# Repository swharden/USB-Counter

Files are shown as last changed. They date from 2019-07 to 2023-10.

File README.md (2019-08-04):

# USB Counter

This project contains the design files and notes for a USB counter. By populating one of two input paths with components this device can serve as a sensitive frequency counter (with a small-signal amplifier front-end) or a pulse counter (with a simple 50 ohm load at the front-end). Measured frequency is sent to the computer over USB, but can also be displayed on an optional 7-segment display module.

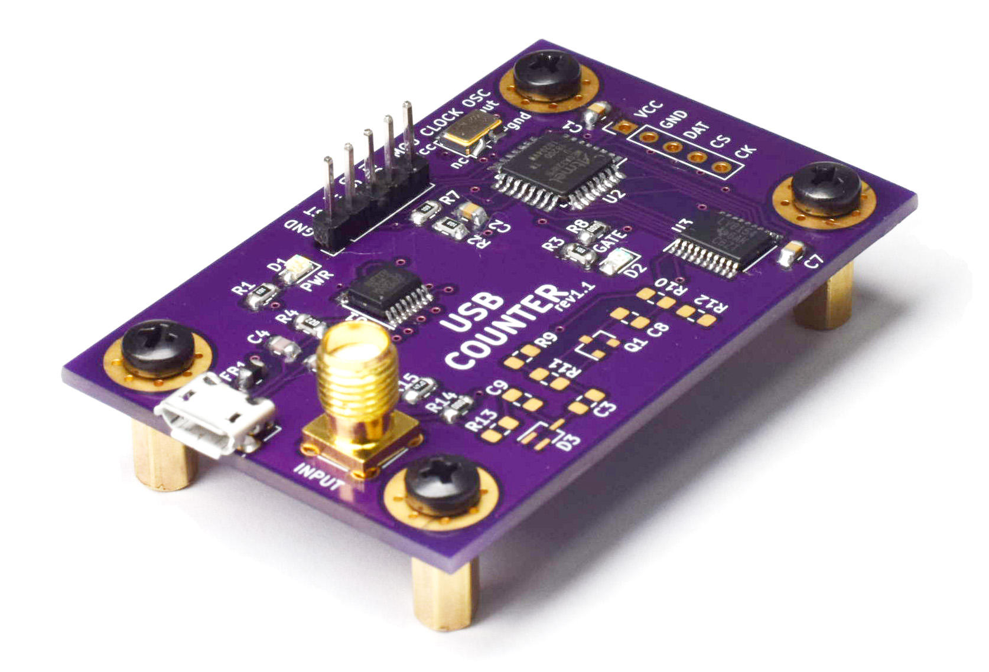
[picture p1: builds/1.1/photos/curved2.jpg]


### LED Display

In addition to serial output, this counter can optionally interface a SPI-driven 7-segment display (based on a MAX7219). These display modules are about [$4 on Amazon](https://www.amazon.com/s?k=max7219+segment) and allow this counter to be used without a computer. Note that the LED display and USB output can both be used at the same time.

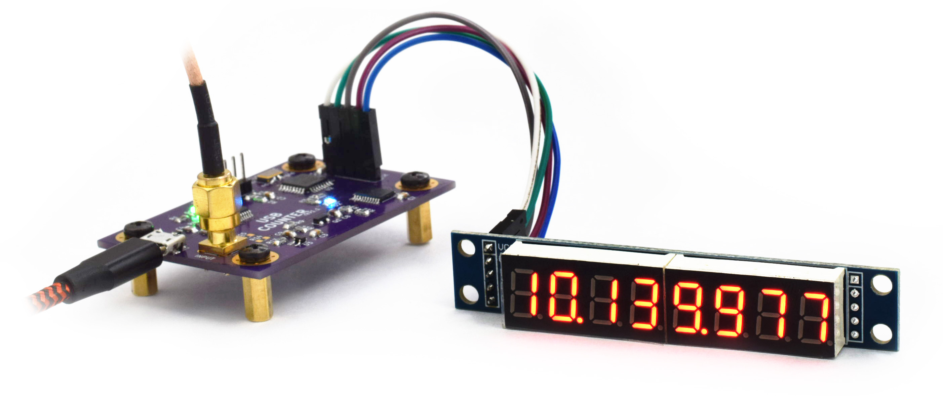
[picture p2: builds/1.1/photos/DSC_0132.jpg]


### USB (Serial) Output

When plugged in to a USB port the counter looks like a serial device. It continuously transmits the count (at 115200 baud) at an update rate which can be customized (commonly 1Hz, 10Hz, and 100Hz.) The output is two numbers: time (in seconds) and the count between the last update and this one. In this example it is measuring a radio frequency signal near 10.139977 MHz

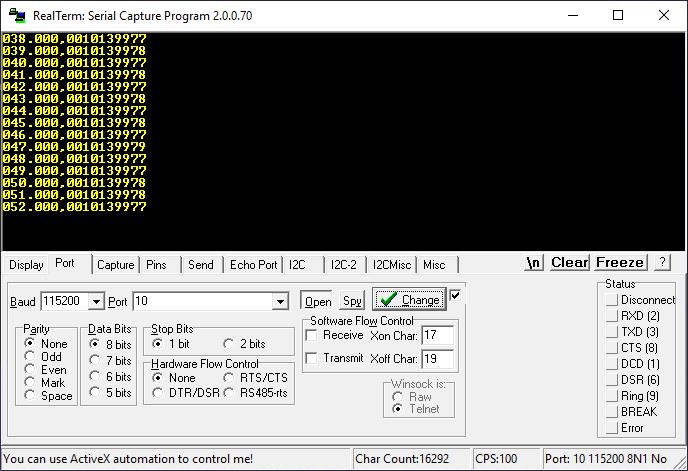
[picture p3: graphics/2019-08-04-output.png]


### Precision Frequency Measurement

One advantage of this counter is that it is never reset. Its core is a 32-bit counter, and every gate cycle transmits the current count to the computer over USB. Because every input cycle is measured high precision measurements of frequency over long periods of time are possible. For example, 1000 repeated measurements with a 1Hz gate allows frequency measurement to a precision of 0.01 Hz.

### Internal or External Gating
The microcontroller is capable of generating gate cycles in software. Precision is limited to that of the TCXO used to clock the microcontroller (2.5 PPM). For higher-precision gating a resistor may be lifted and an external gate applied (e.g., 1PPS GPS signal).

### Design and Build Notes

* [Revision 1.0 - schematics and PCB design](/builds/1.0) - first tested 2019-07-26
* [Revision 1.1 - schematics and PCB design](/builds/1.1) - first tested 2019-08-03

### About

This project was created by [Harden Technologies, LLC](http://tech.swharden.com). To inquire about the development special features or customized versions of this hardware or software, contact the author at [SWHarden@gmail.com](mailto:swharden@gmail.com).

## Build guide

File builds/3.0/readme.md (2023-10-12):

# Talking Frequency Counter

This version of the frequency counter uses USB for power (not connectivity) and speaks frequency out loud when a button is pressed. Once finished this project will probably be moved into its own repository.

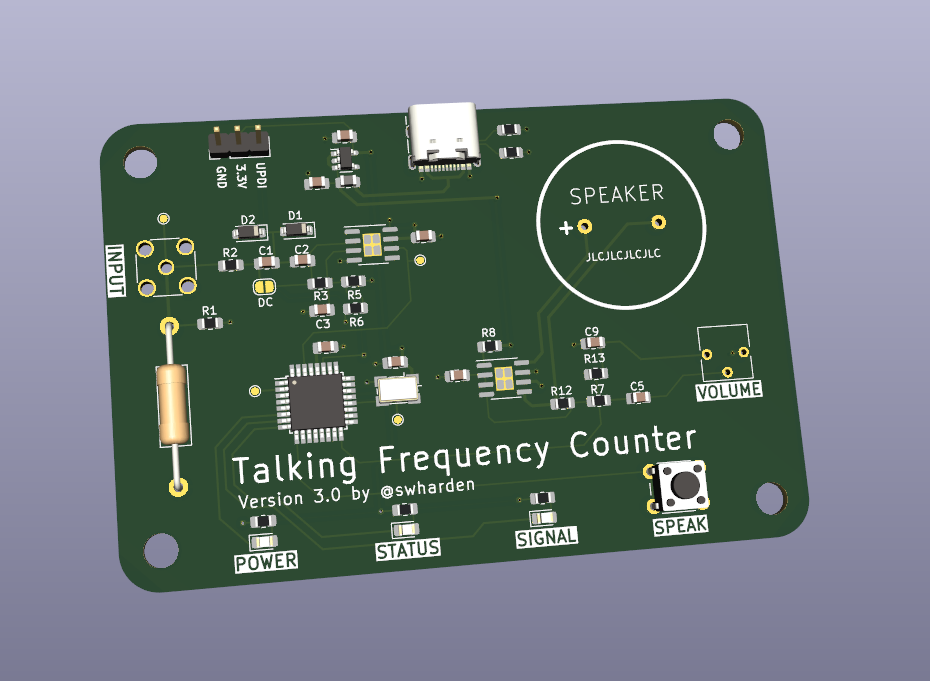
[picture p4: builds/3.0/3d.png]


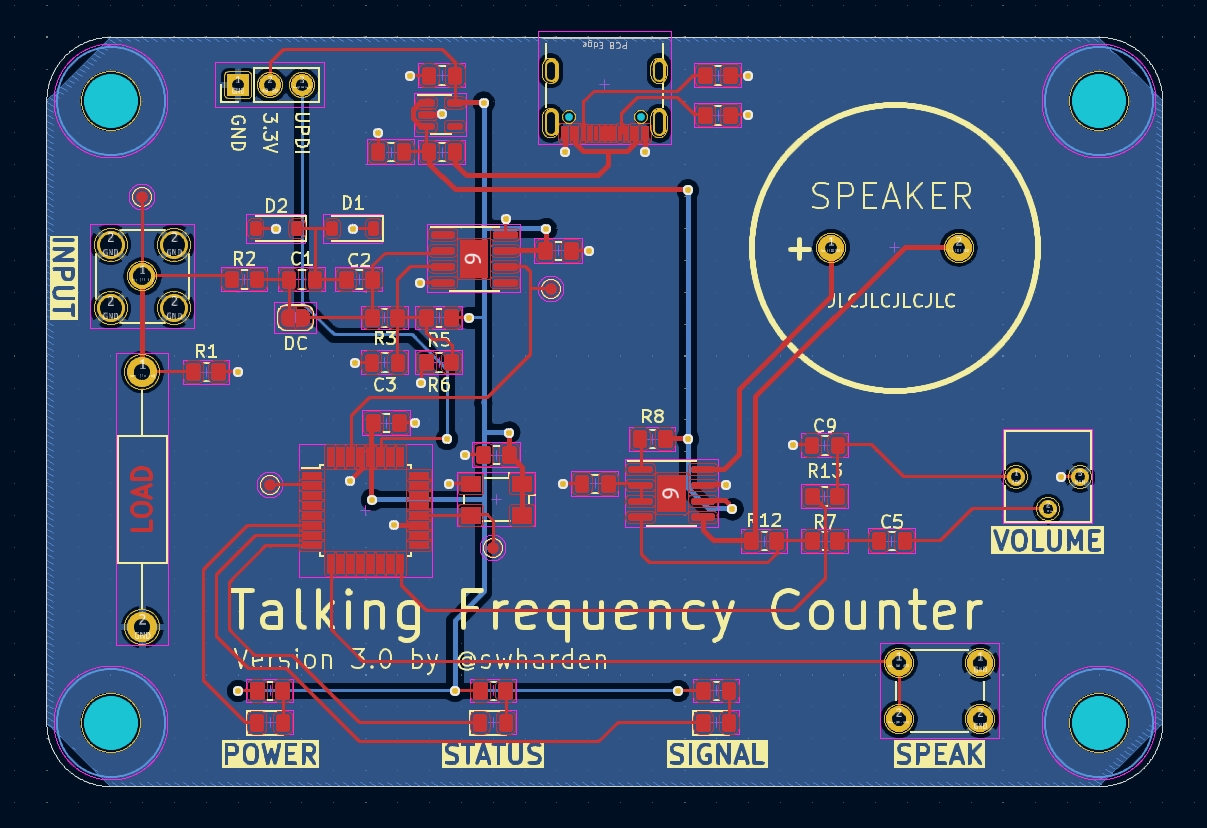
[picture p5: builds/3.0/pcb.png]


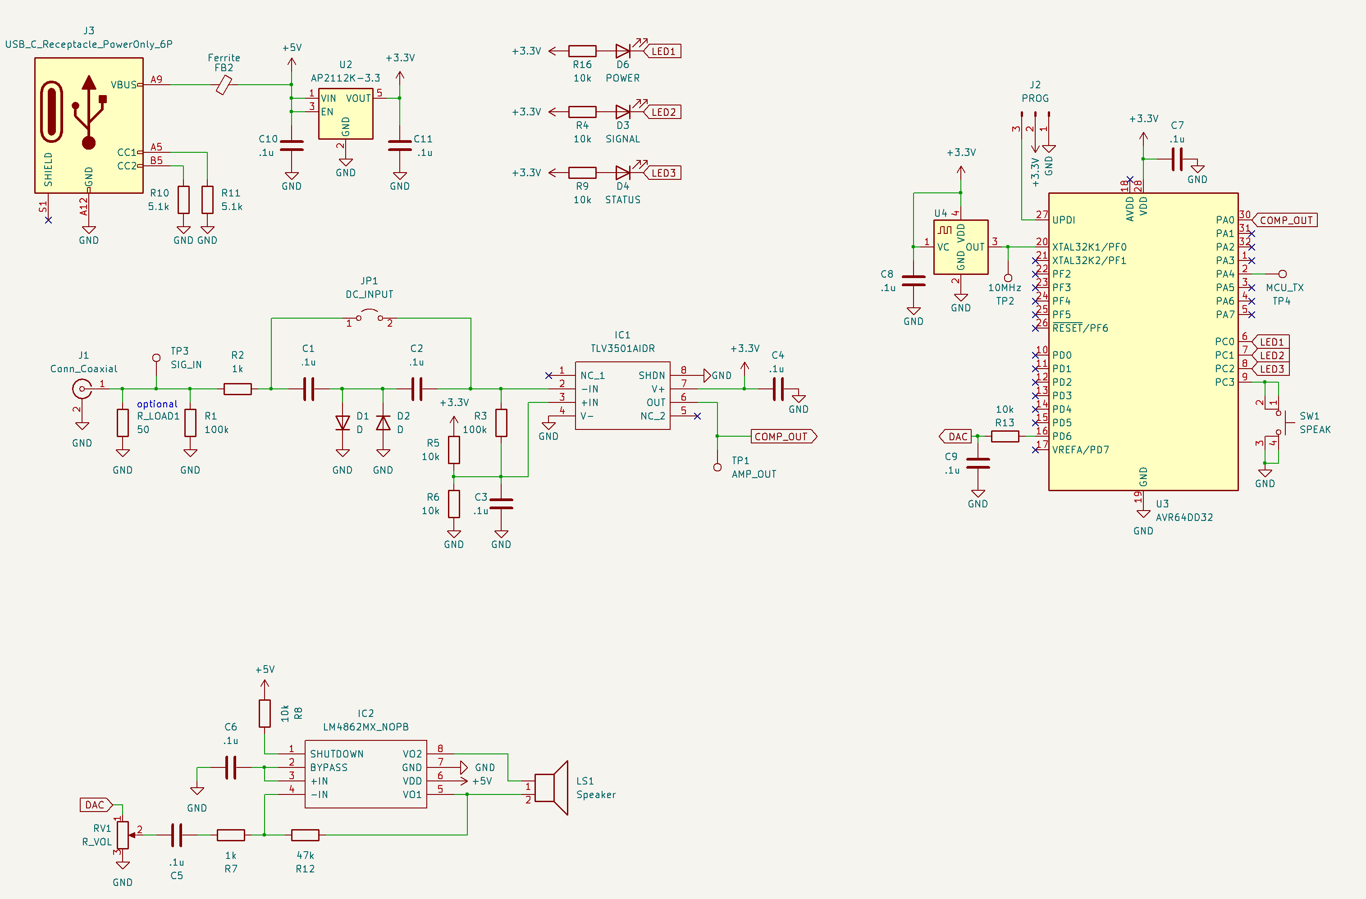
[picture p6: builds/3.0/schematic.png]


## Build Notes

* VDDIO2 should be connected to 3.3V (required bodge wire)
* Crystal pads are silly big
* Audio amplifier shutdown should be pulled LOW not HIGH
* Volume knob is wired backwards
* Rename header 3.3v to VCC
* Button is wired incorrectly (always grounded)
* Move header closer to the edge or use different system
* Don't use port C for LEDs or button

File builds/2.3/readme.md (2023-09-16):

# Talking Frequency Counter

This folder contains design notes for a ***talking frequency counter*** designed to help visually impaired radio operators to know what frequency they are transmitting on by speaking the frequency out loud when a button is pressed. This design uses a high-speed analog comparator to amplify signals on the frontend, measures them directly with a microcontroller, sends that data to a PC using a USB serial adapter, and also says the frequency out loud using a speaker.

> **⚠️ WARNING:** This is a work in progress. This board design has some errors which will be corrected in a future build.

## Components
* **AP2112K-3.3TRG1** 600 mA 3.3V LDO regulator ([$0.35 from Mouser](https://www.mouser.com/ProductDetail/Diodes-Incorporated/AP2112K-3.3TRG1?qs=x6A8l6qLYDDPYHosCdzh%2FA%3D%3D))
* **AVR64DD32** 8-bit microcontroller ([$1.51 on Mouser](https://www.mouser.com/ProductDetail/Microchip-Technology/AVR64DD32-I-PT?qs=tlsG%2FOw5FFjuwvYsegdIqg%3D%3D))
* **Oscillator** 10 MHz oscillator, 3.3V, ±2.5 ppm ([$1.89 on Mouser](https://www.mouser.com/ProductDetail/ECS/ECS-TXO-2016-33-100-TR?qs=PzGy0jfpSMvd6OxkHIkpfg%3D%3D))
* **TLV3501** high speed analog comparator ([$3.06 on Mouser](https://www.mouser.com/ProductDetail/Texas-Instruments/TLV3501AIDR?qs=m96fseALk3U7ir0PfDMQ%252BA%3D%3D))
* **LM4862** audio amplifier ([$1.21 on Mouser](https://www.mouser.com/ProductDetail/Texas-Instruments/LM4862MX-NOPB?qs=QbsRYf82W3HZp12WHQE14A%3D%3D))
* **FT231** USB Serial Adapter ([$2.33 on Mouser](https://www.mouser.com/ProductDetail/FTDI/FT231XS-R?qs=Gp1Yz1mis3WduRPsgrTbtg%3D%3D))
* **Diode** 100V 4A 4ns recovery ([$0.13 on Mouser](https://www.mouser.com/ProductDetail/Panjit/1N4148W_R1_00001?qs=sPbYRqrBIVnqVztCqPNVrw%3D%3D))
* **Speaker** 8Ω 300 mW ([$2.09 on Mouser](https://www.mouser.com/ProductDetail/DB-Unlimited/SM231508-1?qs=t9M3m0YJX4Ng139DBuQXjw%3D%3D))
* **USB Connector** type B micro ([$0.46 on Mouser](https://www.mouser.com/ProductDetail/Amphenol-FCI/10118193-0001LF?qs=Ywefl8B65e63Nsqd%252B8HZaQ%3D%3D))
* **USB Connector (next time)** use USBC ([$0.80 on Mouser](https://www.mouser.com/ProductDetail/GCT/USB4105-GF-A?qs=KUoIvG%2F9IlY%2FMLlBMpStpA%3D%3D))
* **0802 Components** are purchased in bulk and essentially free
* **Bumpers** for raising the PCB ([Bumpon SJ5076 from eBay](https://www.mouser.com/datasheet/2/1/Bumpon%20Molded%20Shapes%20Colored%20and%20Clear%20Series%20TDS-845047.pdf))

_Approximately $13 total_

## Schematic

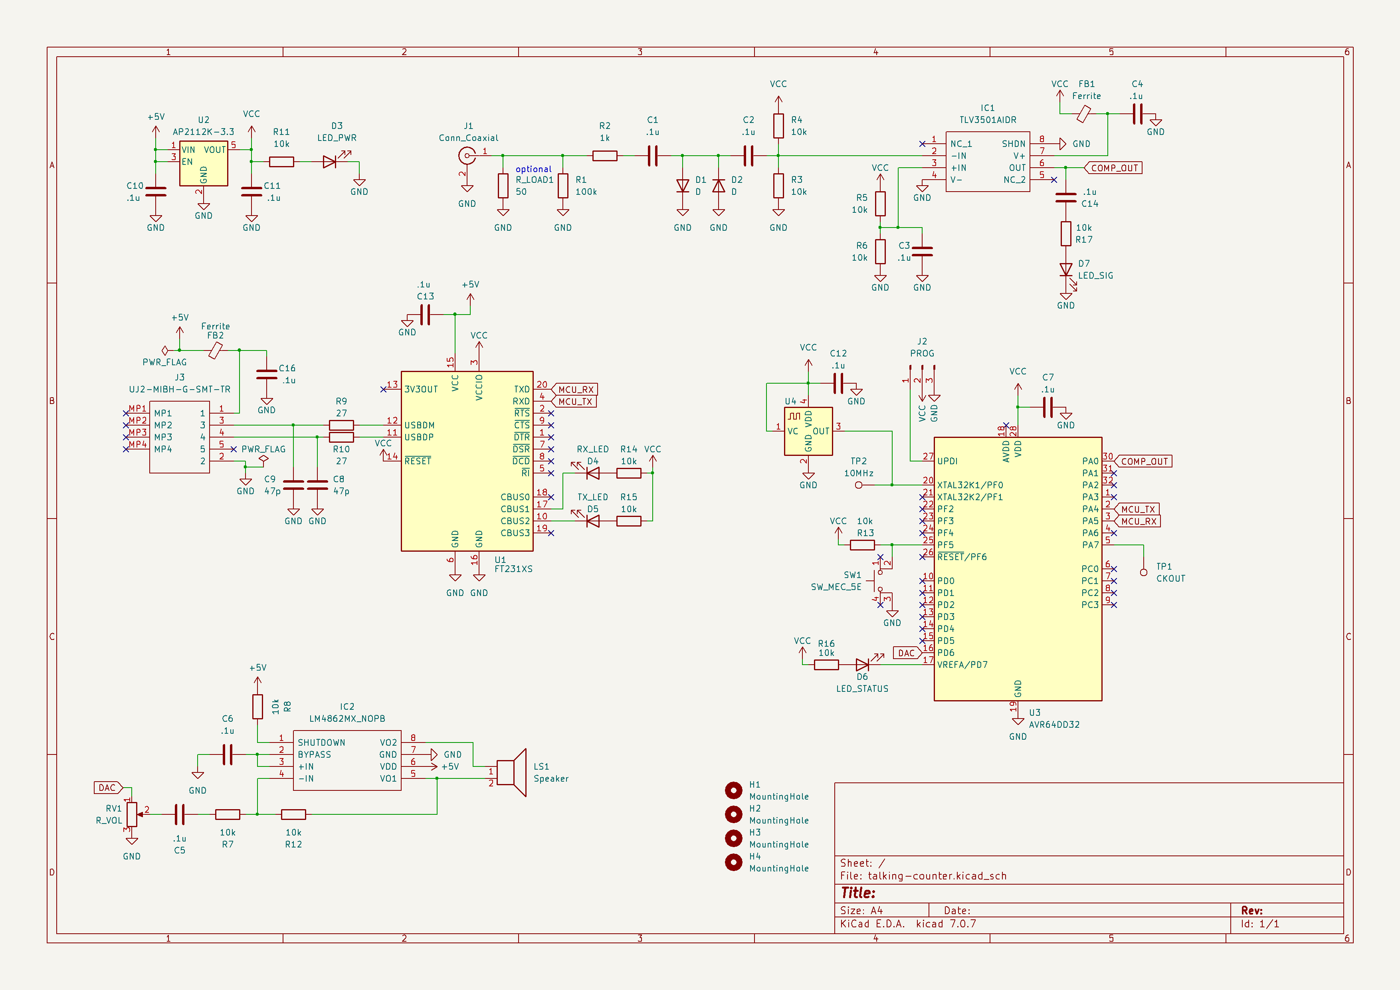
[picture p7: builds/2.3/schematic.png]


## Preview Render

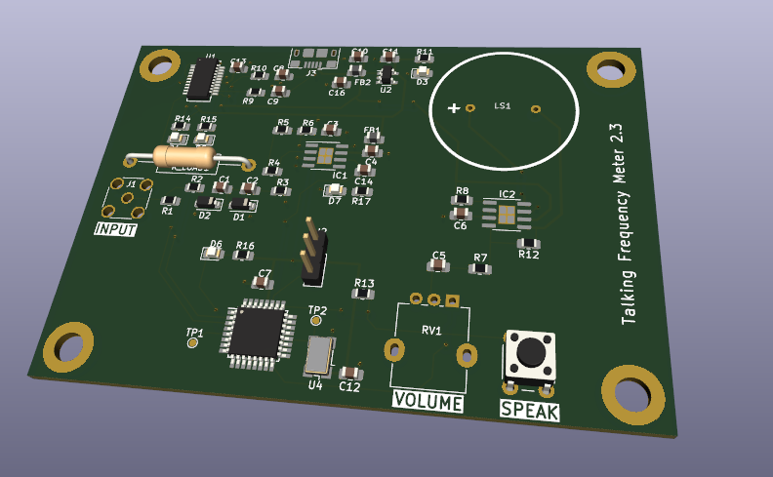
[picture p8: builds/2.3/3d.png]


## Resources

* [100 MHz frequency counter](https://www.electronics-lab.com/project/100mhz-frequency-counter-with-pic16f628a-2/) (designed by Hristo) uses the TLV3501 for its frontend

* [Frequency Measurement with Modern AVR Microcontrollers](https://swharden.com/blog/2023-08-31-avr-dd-frequency-counter/)

* [Play Audio from SPI Flash with a Microcontroller](https://swharden.com/blog/2023-08-26-spi-flash-audio/)

* [Speaking Numbers with a Microcontroller](https://swharden.com/blog/2023-08-19-speaking-microcontroller/)

## Photo

Oof that's a lot of bodges

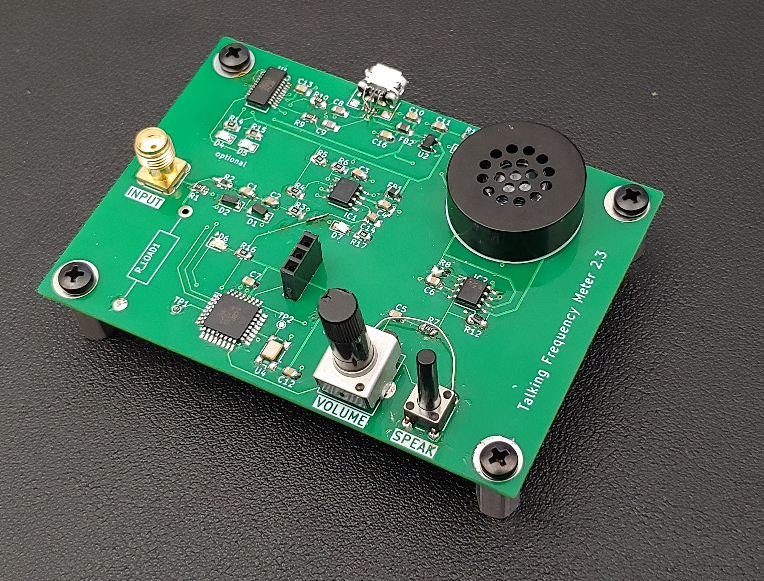
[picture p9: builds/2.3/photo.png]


## Notes During the Build
* PCB edges should be rounded
* Green LEDs should have 47k resistors (not 10k)
* USB lines are incorrect. They should be:
  * 1. VCC
  * 2. ?
  * 3. ?
  * 4. ID (nc)
  * 5. GND
* Need to order more .1 µF caps
* Speaker holes should be bigger
* Volume knob holes should be bigger
* Volume knob polarity should be reversed
* Label programmer pins
* Amplifier shutdown pin should be grounded (not tied to VCC)
* Amplifier resistors should be R12=47k and R7=1k
* The button is wired wrong. Bottom right pin should be grounded.
* Test points should be labeled.
* Add a test point for comparator input and output.
* Ground screw holes.
* Omit RX led (only TX needed)
* Use smaller volume knob and move it away from the button
* Speaker hides power LED
* Move prog header to edge of board
* The load resistor "optional" label is floating beneath the RX/TX leds
* Omit C14 and replace R17 with a 1k resistor
* Use green LEDs everywhere
* Fix the double-press issue
* RF front-end: use a dual diode
* RF front-end: don't tap COMP_OUT with a LED (do that in software)
* Just add TX test pad (not FTDI chip)
* Load comparator output
* Jumper to bypass AC coupling on input

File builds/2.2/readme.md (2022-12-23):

# Version 2.2

## Thoughts

* Make an RF amplifier board separately (perhaps with prescaler)
* Input should be 0-5V TTL
* What makes this unique is no-cycle-lost counting
* Ability to accept a 10 MHz lab reference clock is also a big win

## Build notes
* Red and blue LEDs need 1K resistors
* Green LEDs need 47k resistors
* Capacitors on USB line should be 47pF
* LJCPCB blue silkscreen is ugly and doesn't hold up to heat as well as green
* For the crystal oscillator indicate where the dot goes
* It's annoying to keep rotating the board when hand assembling so lay-out passives horizontally
* Move the board ID under one of the ICs
* Consider horizontally mounted headers and SMA connector to facilitate stacking
* Clamp diodes should be downstream of the input decoupling decapacitors
* External 10MHz clock is going into the wrong pin (32 kHz clock). Clock should go to PA0/PA1 and USART use alternate pins PD4/PD5

## Schematic

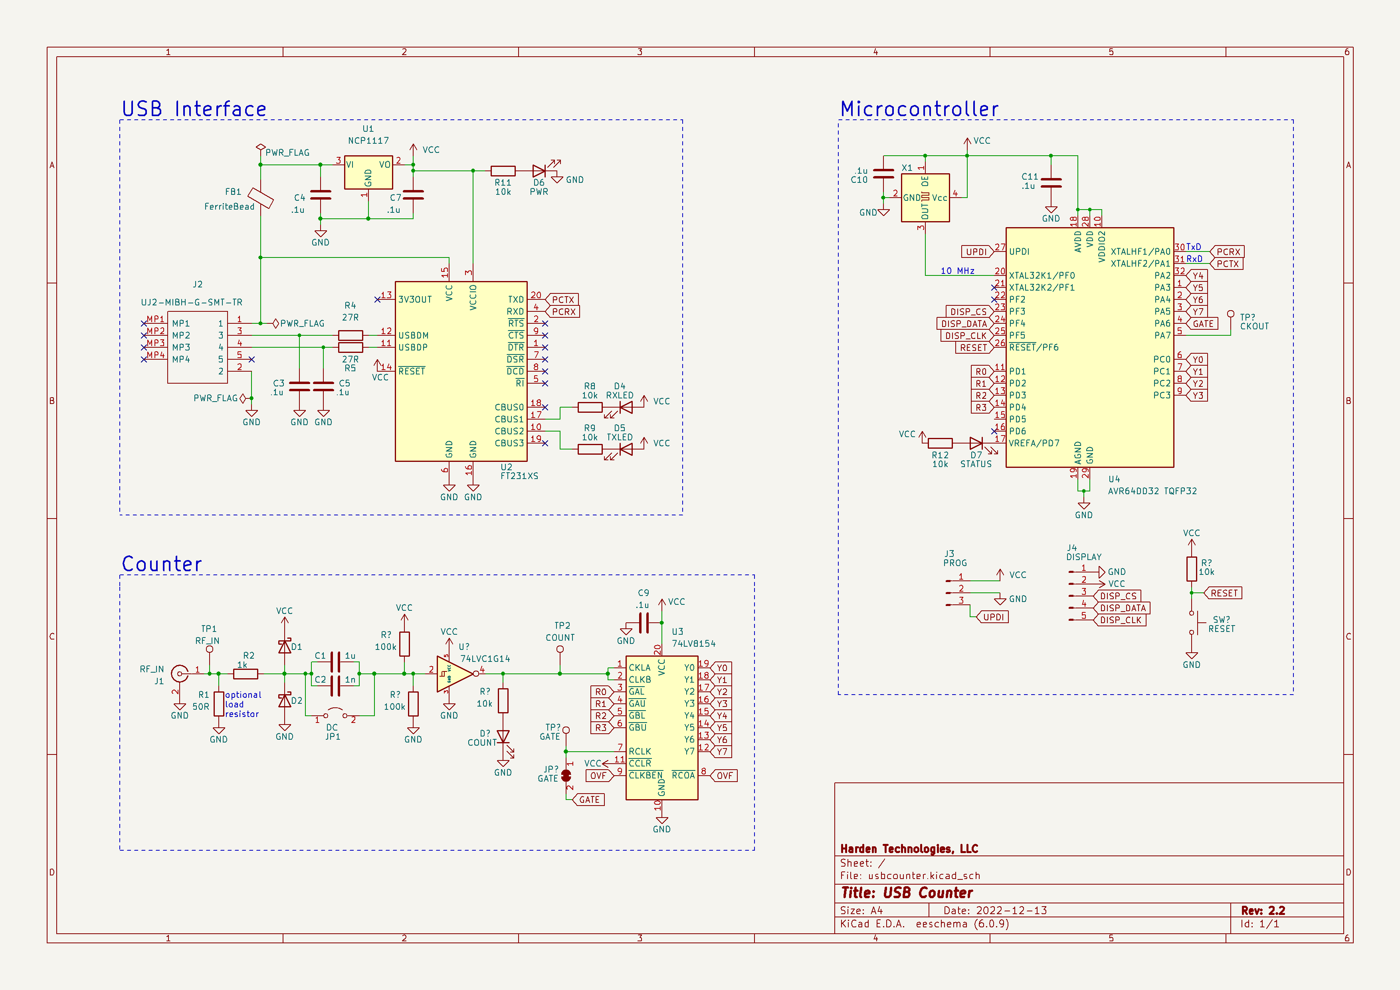
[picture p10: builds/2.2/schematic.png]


## Alternative Frontend Designs

### TLV3501 RF Comparator
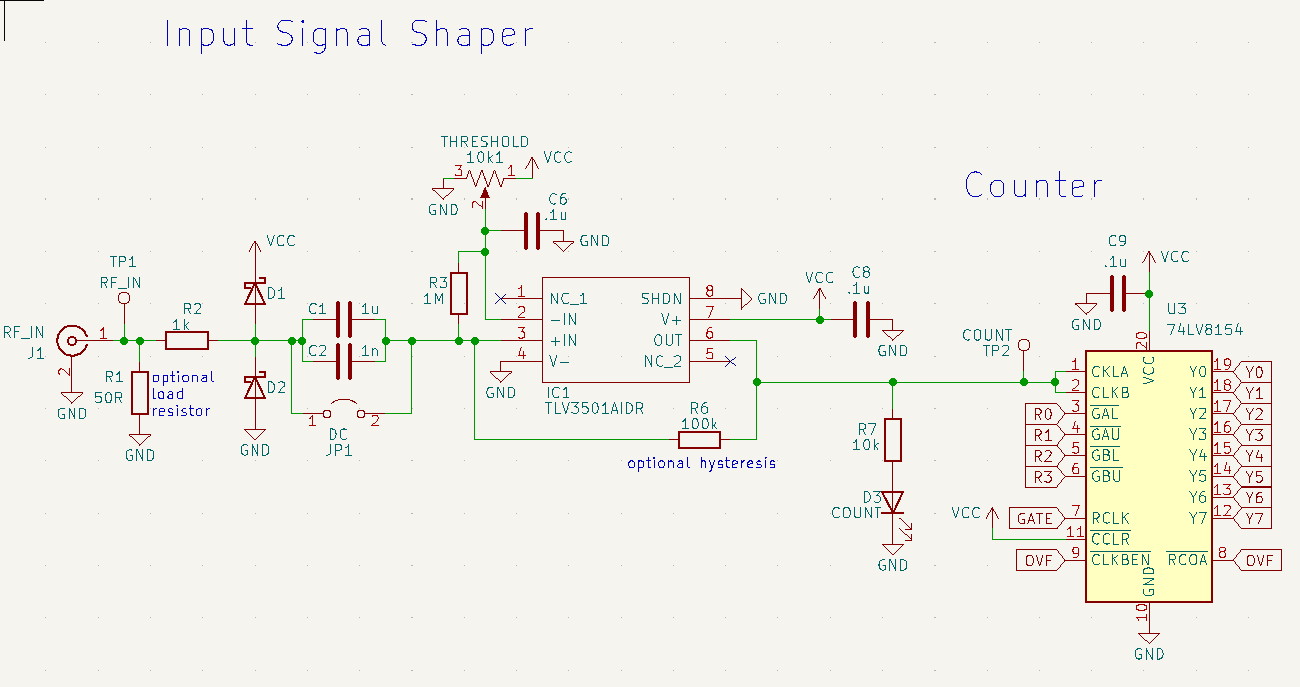
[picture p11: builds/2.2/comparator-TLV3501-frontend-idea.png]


### OPA356 RF Opamp
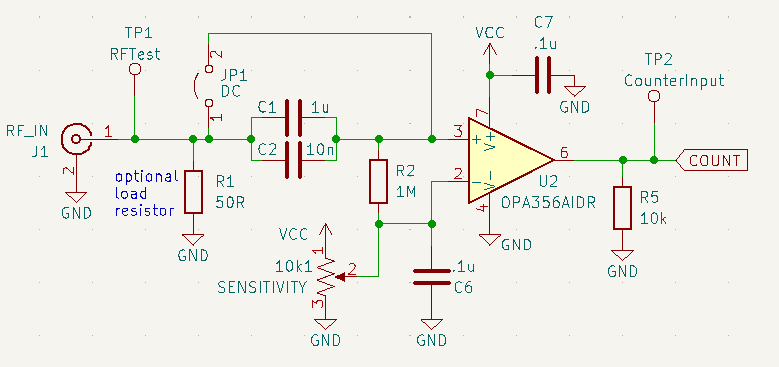
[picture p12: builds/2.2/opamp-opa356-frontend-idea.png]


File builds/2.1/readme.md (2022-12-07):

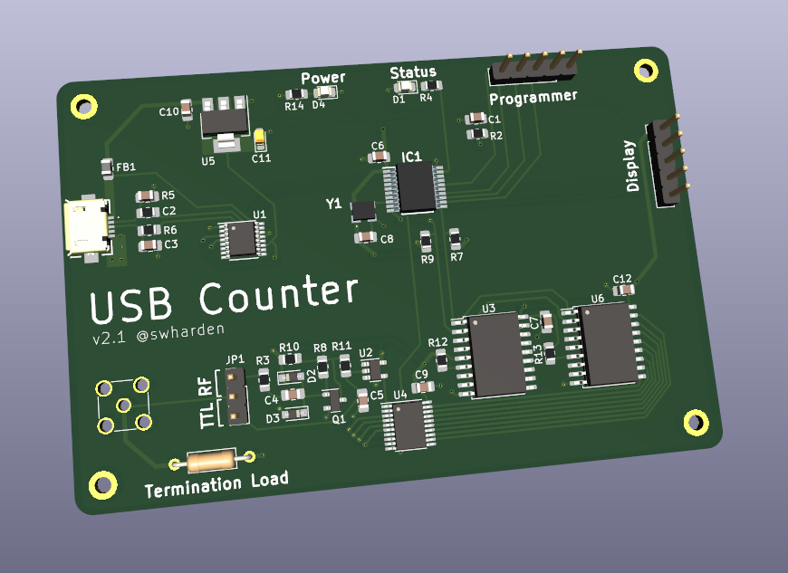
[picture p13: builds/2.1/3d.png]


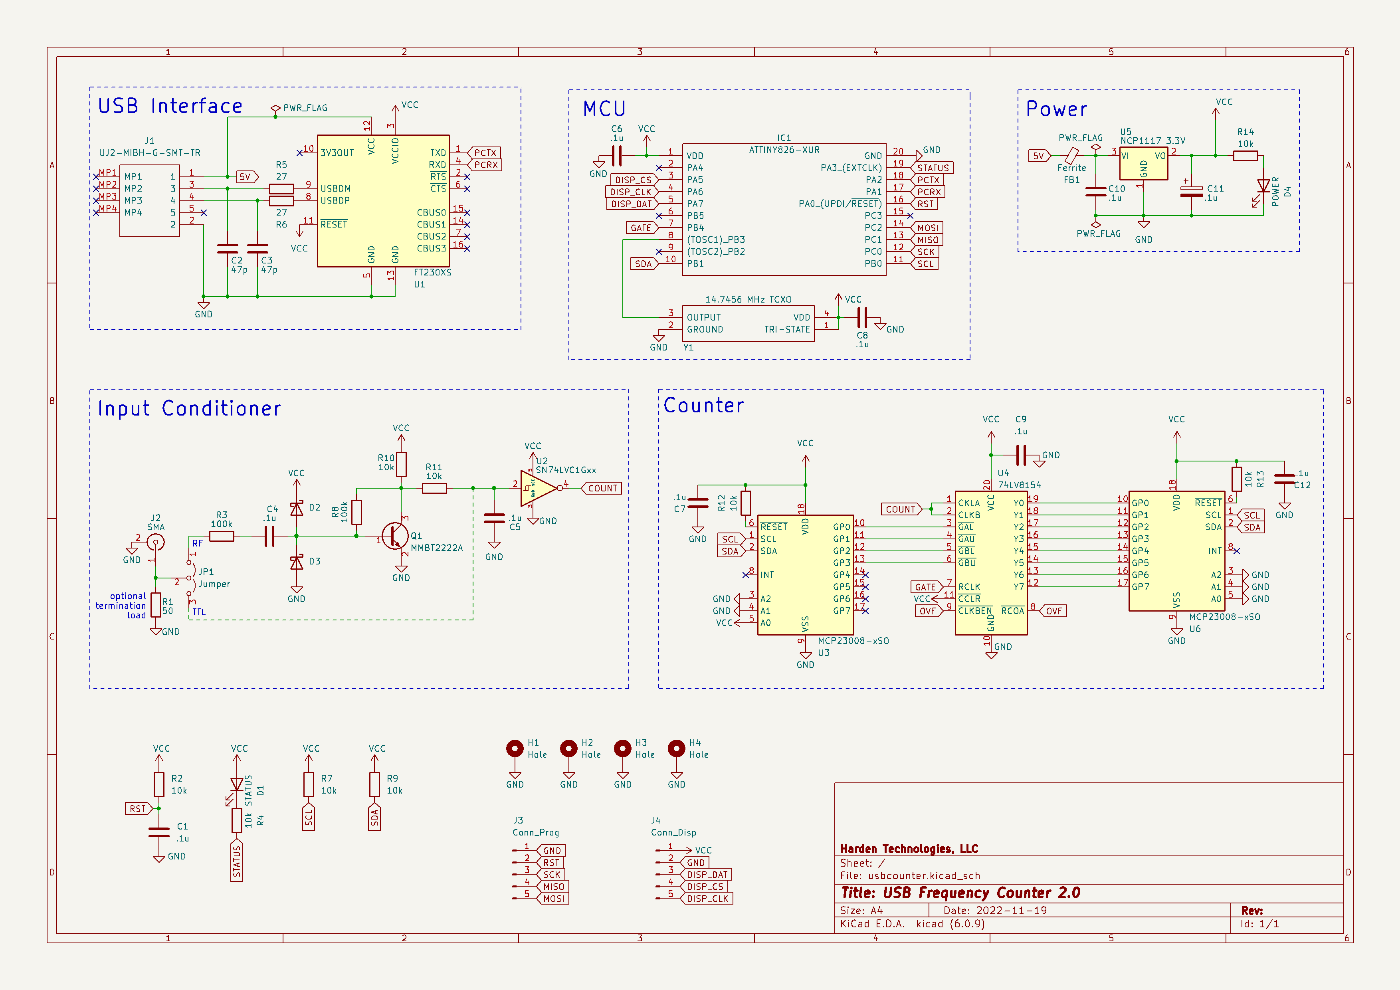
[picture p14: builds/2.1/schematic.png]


## Notes

* Design around FT231 (not FT230) for improved supply chain availability
* PCB labels for R5 and C2 are reversed
* ICs need dot near pin 1
* favor USBC port
* dot for oscillator
* screw holes are too small
* pins need labels
* MCU programming pins are wrong - this chip only supports UPDI
* Frontend sucks. Check out better [buffer](http://www.muzique.com/lab/buffers.htm) frontends.

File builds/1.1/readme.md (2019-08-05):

# USB Frequency Counter (rev 1.1)

* I ordered this PCB on 2019-07-28
* I built this device on 2019-08-03

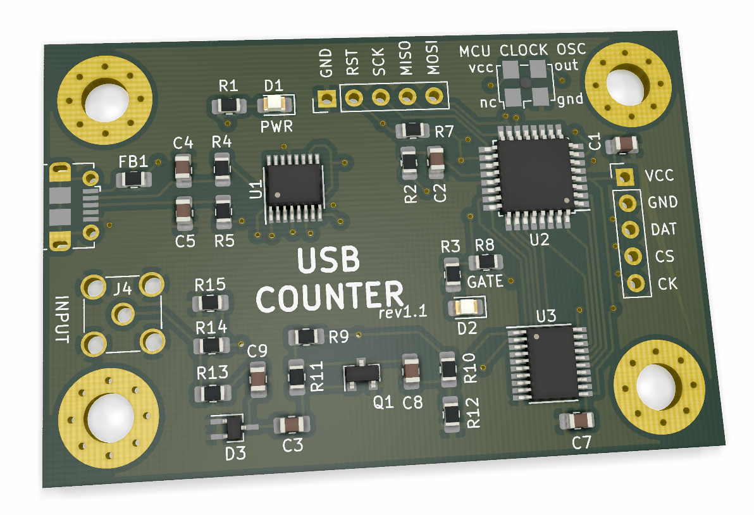
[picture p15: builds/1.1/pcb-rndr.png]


### PCB Design
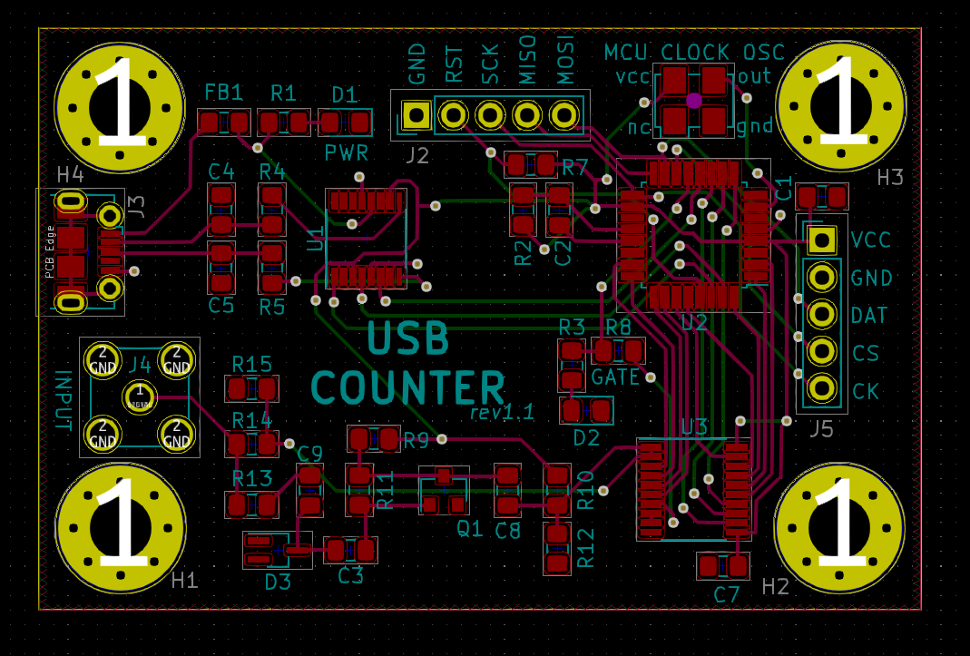
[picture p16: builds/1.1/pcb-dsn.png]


### Schematic
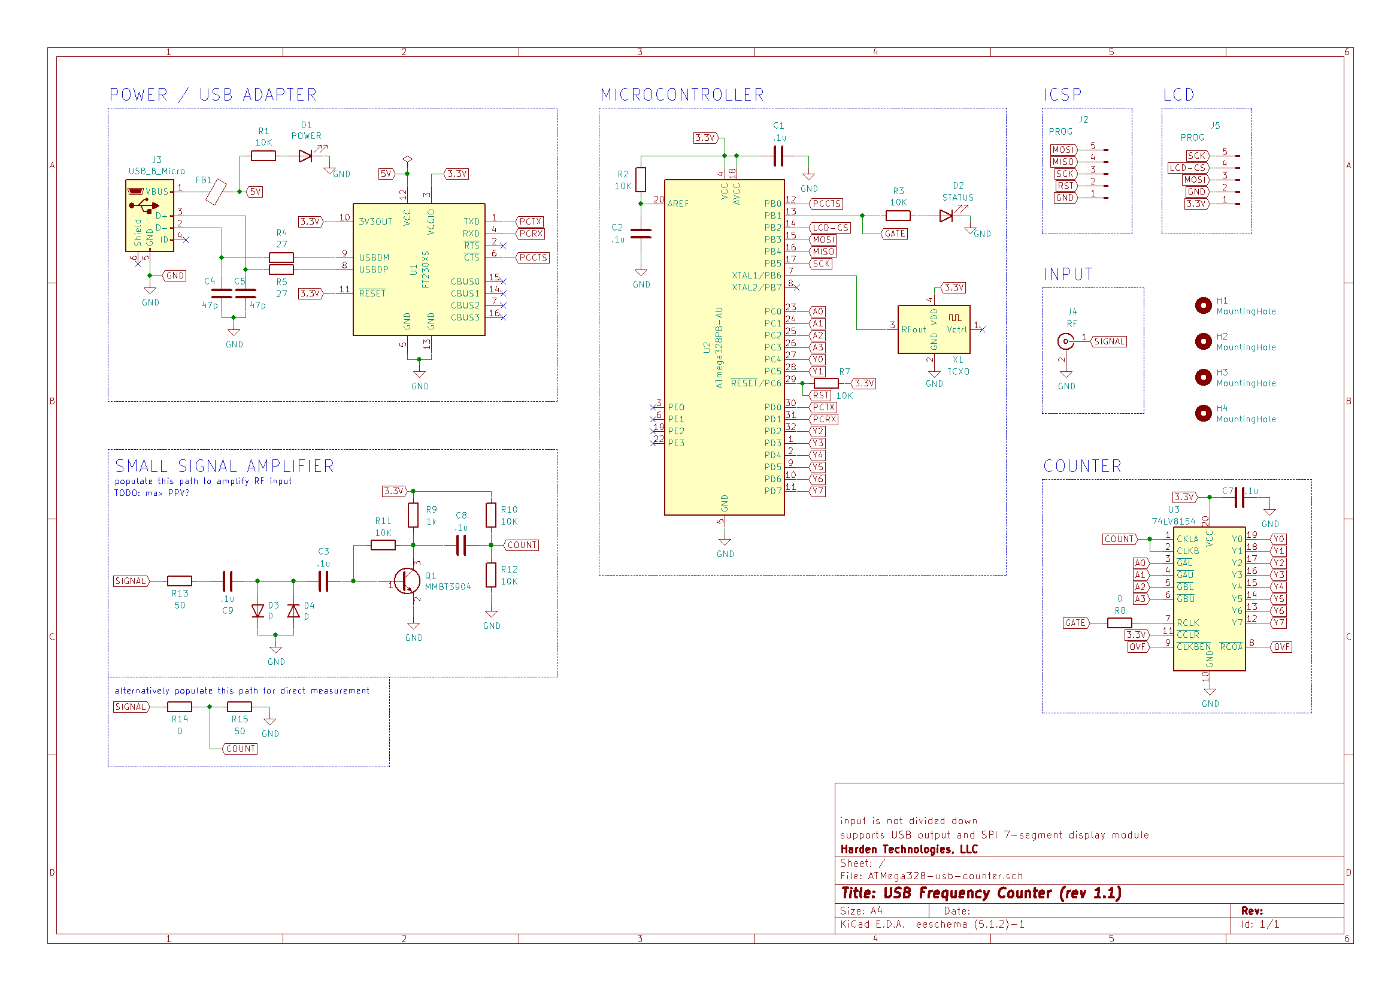
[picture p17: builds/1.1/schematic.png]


## Changes from rev 1.0
* improved RF amplifier design
* alternate path to bypass RF amplifier
* corrected counter pin connections
* free a MCU pin by making the status LED the gate
* add a header for the serial LED display
* run MCU at 14.7456 MHz
  * allows much faster serial transmission
  * no longer accepts external 10MHz reference
  * may still accept external gate
* added screw holes
  * they're floating (not grounded) - should they be grounded?
* switched to micro USB (from mini USB)

## Components
* all passives are 0805 (~$1)
* [SBAV99WT1G SC-70 dual diode](https://www.mouser.com/ProductDetail/ON-Semiconductor/SBAV99WT1G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) 215 mA ($0.29)
* [14.7456MHz TCXO](https://www.mouser.com/ProductDetail/Fox/FOX924B-147456?qs=sGAEpiMZZMt8oz%2FHeiymADfzZKRiEXclvcmWd5jLzoM%3D) 2.5 PPM, 14.7456MHz ($2.36)
* [SN74LV8154](https://www.mouser.com/ProductDetail/Texas-Instruments/SN74LV8154PWR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) ($0.99) TSSOP-20
* [FT230XS-R](https://www.mouser.com/ProductDetail/FTDI/FT230XS-R?qs=sGAEpiMZZMtv%252Bwxsgy%2FhiIaF6qCroMVR1i2pEQA5UpU%3D) ($2.04) SSOP-16
* [ATMega328](https://www.mouser.com/ProductDetail/Microchip-Technology-Atmel/ATMEGA328PB-AU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) ($1.38)
* [mini-USB jack](https://www.mouser.com/ProductDetail/CUI/UJ2-MBH-1-SMT-TR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) ($0.49)
* [micro-USB jack](https://www.mouser.com/ProductDetail/Hirose-Connector/ZX62D-B-5PA830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) ($0.70)
* [SMA connector](https://www.mouser.com/ProductDetail/LPRS/SMA-CONNECTOR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) ($1.08)
* [SPI-driven 8-digit 7-segment display module](https://www.amazon.com/dp/B07CL2YNJQ) ($13 for 4)

## Build Notes
* didnt have 27 ohm resistors. used 22 ohm.
* I used a 500mW rated R15
* I used a 500mW rated R13
* make hand solder version of usb
* make oscillator fit less awkwardly
* Add a 7805 so 12V can be applied or USB. Use a 78L33 (not the reg on the FTDI chip) to power everything else.
* This device doesn't work when plugged into a wall USB cord (power only, no data). It seems an active USB connection is required to cause the 3.3V regulator (built into the FTDI chip) to deliver power. The next revision should use a discrete 3.3V regulator.
* For a standalone (LED) device no USB connection is needed. Make a version that accepts 12V and displays the result on the LED. Make the optional external gate easy to access. Break-out the TX pin so PC logging is still very easy.

## Photos
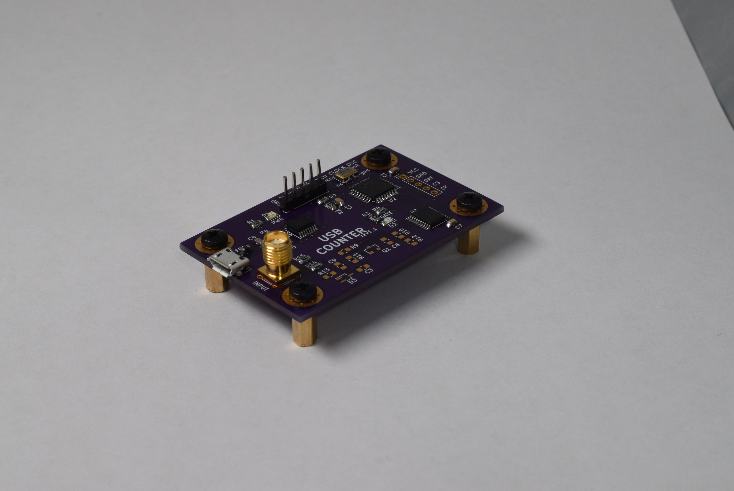
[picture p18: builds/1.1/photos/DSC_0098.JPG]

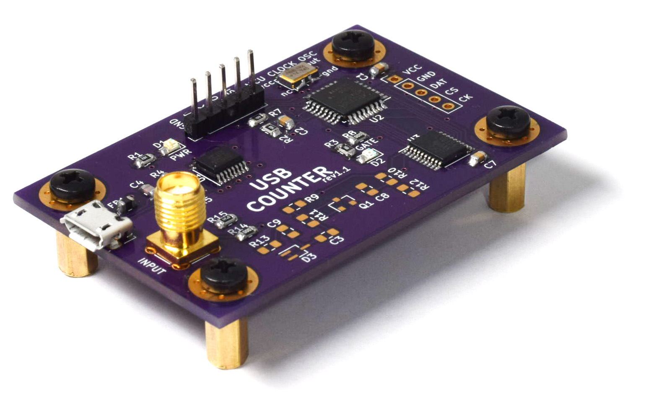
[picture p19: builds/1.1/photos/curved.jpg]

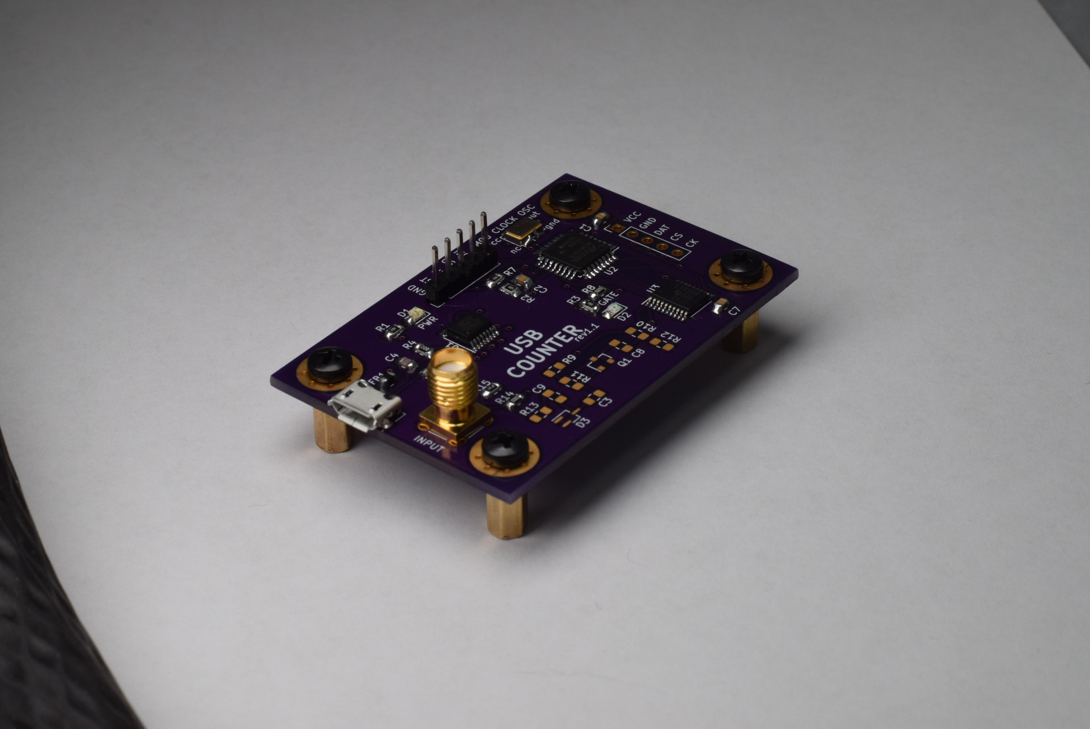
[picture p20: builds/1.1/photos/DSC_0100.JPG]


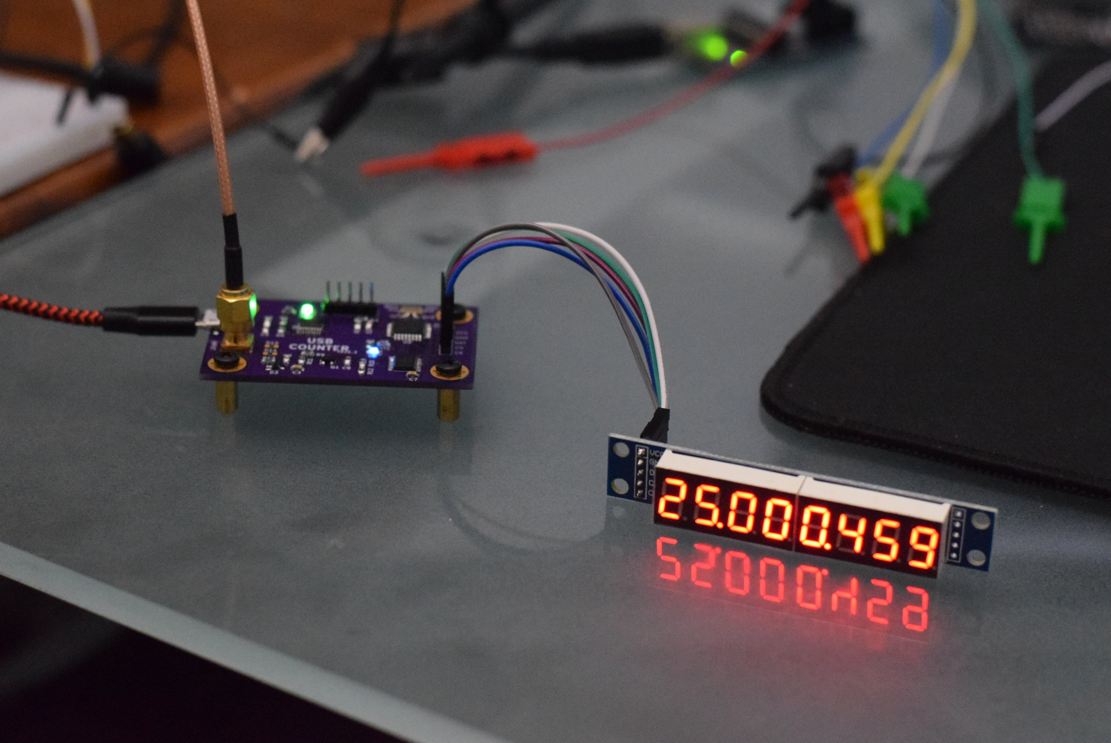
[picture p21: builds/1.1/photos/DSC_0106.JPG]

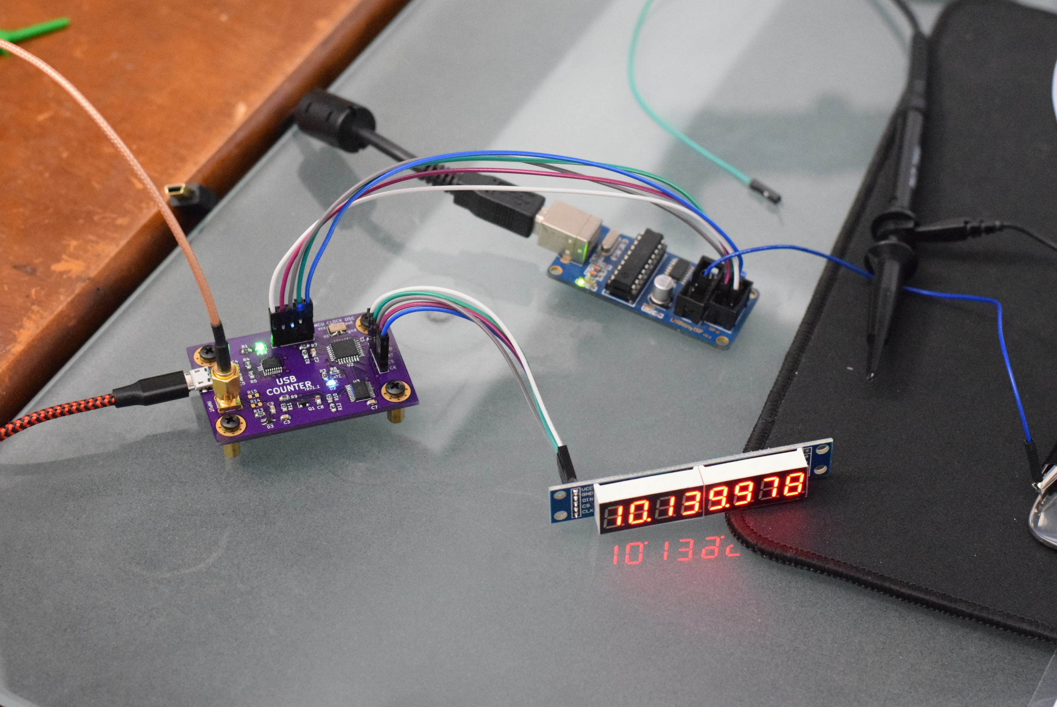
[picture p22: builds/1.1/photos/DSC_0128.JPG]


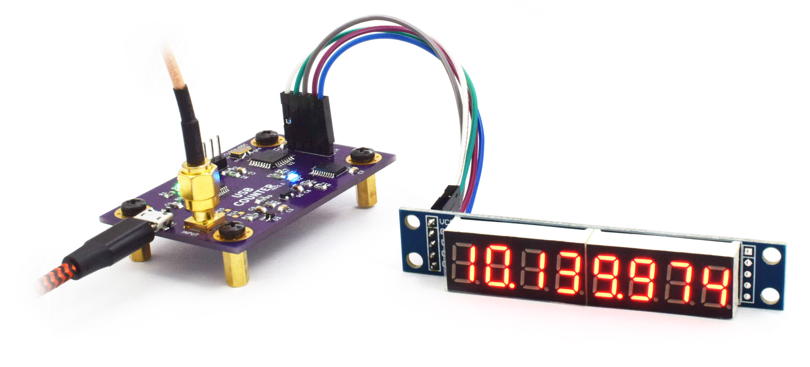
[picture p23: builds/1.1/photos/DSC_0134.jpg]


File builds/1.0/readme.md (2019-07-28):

# USB Frequency Counter (rev 1.0)

This project contains the design and microcontroller code for a USB logging frequency counter. The entire project is open source (open software / open hardware). This project developed from a discussion that started [here](https://github.com/swharden/AVR-projects/issues/1).

The current PCB fabrication cost at OSHPark is $17.40 for 3 ($5.80 each)

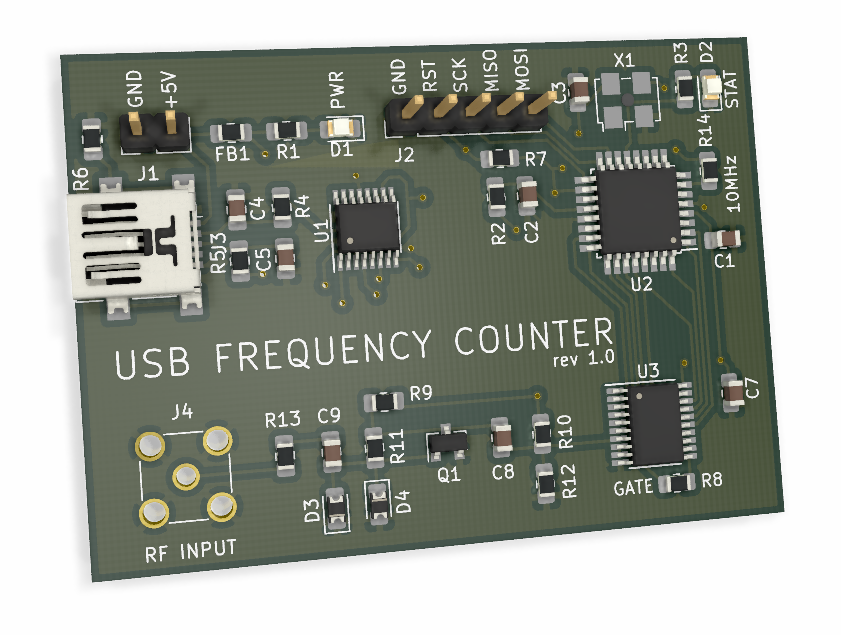
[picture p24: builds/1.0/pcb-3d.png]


### PCB
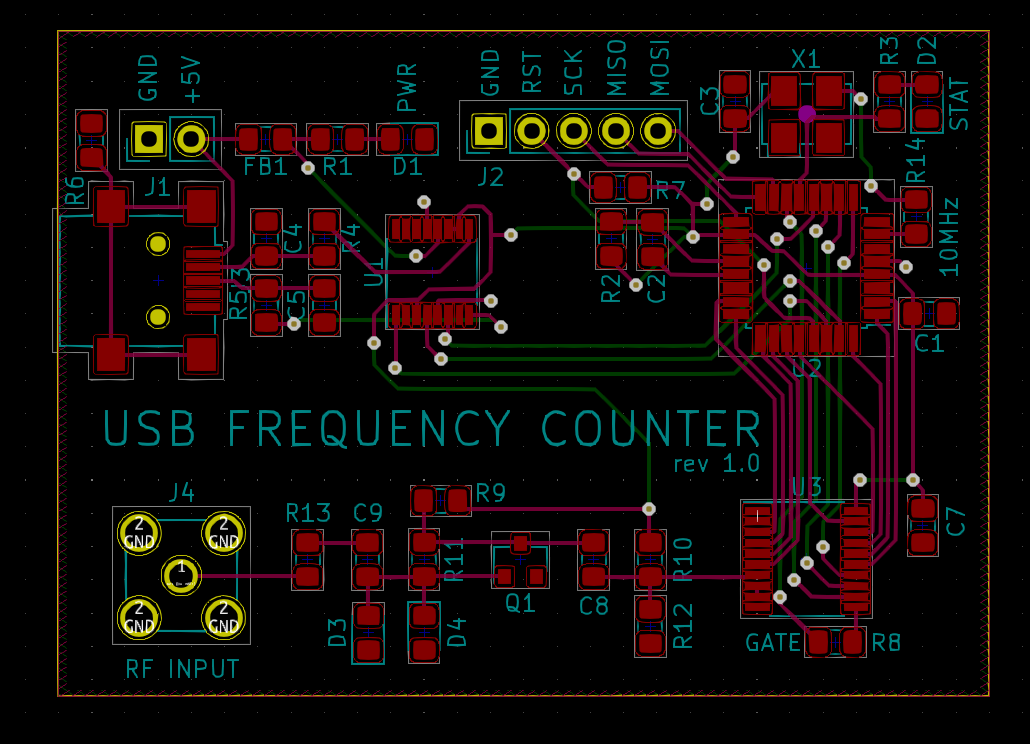
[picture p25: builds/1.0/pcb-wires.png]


### Schematic
See Rev2 notes below for thoughts regarding changing resistor values for the front-end
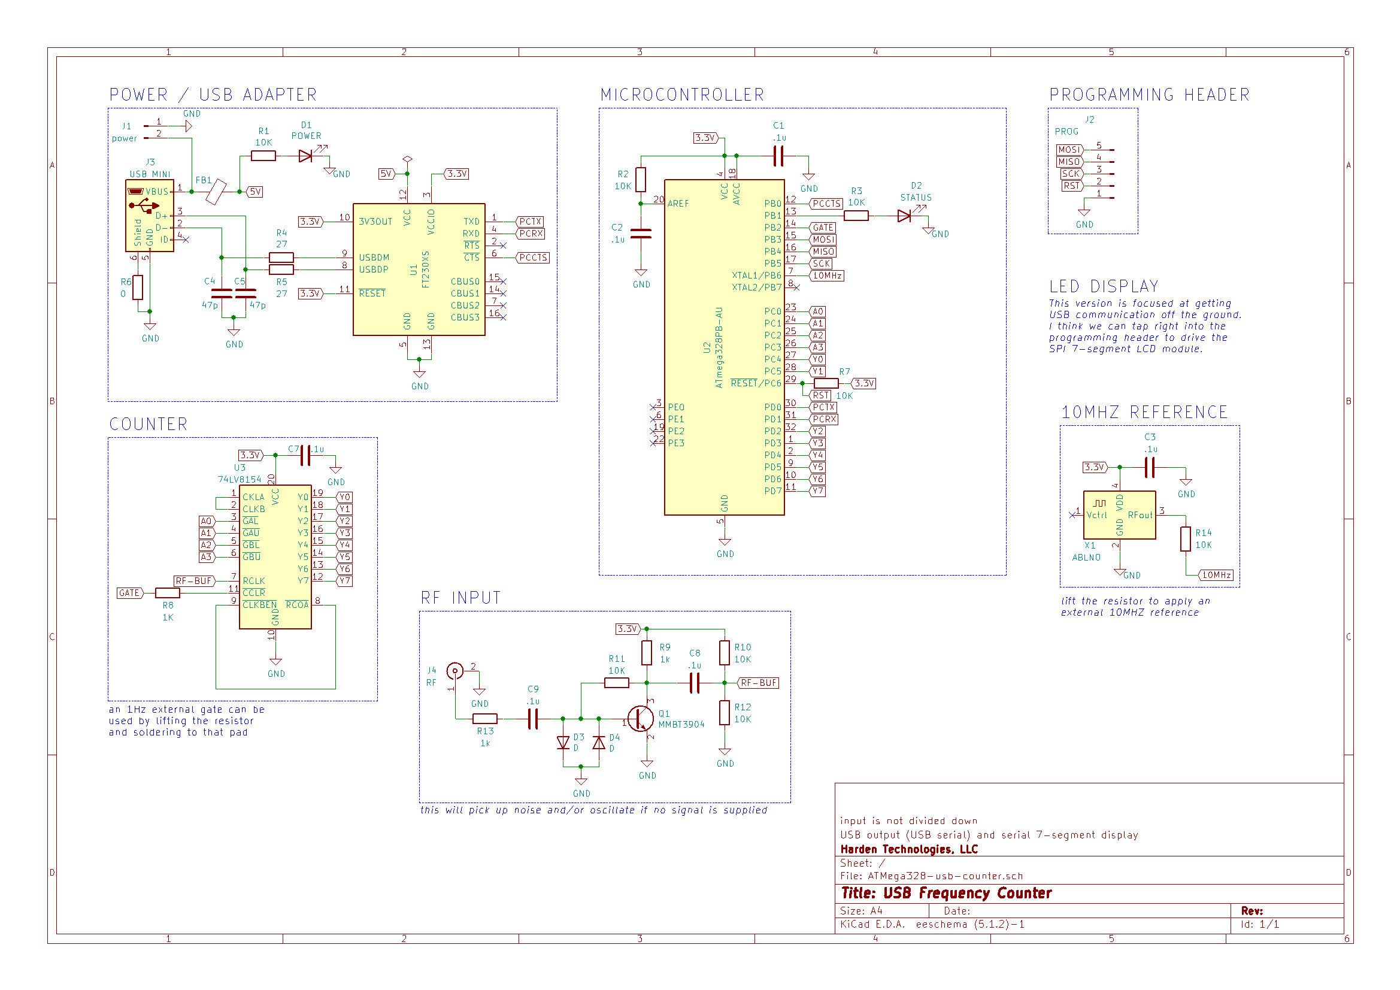
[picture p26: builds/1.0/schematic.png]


## Features
* USB connection allows PC monitoring/logging of frequency
* USB connection not required
  * can be alternatively powered through the 5V pins
  * a SPI-driven 7-segment led module can display frequency
* can use external 10MHz reference
  * don't populate X1, C3, or R14
  * apply 10MHz TTL to the R14 pad
* can use external gate
  * don't populate R8
  * apply 1Hz TTL to the R8 pad
* input signal is amplified and protected (up to 30V)
* no prescaling of input signal
  * every single cycle is counted over extended periods of time
  * cycles not counted in one gate tick roll-over to the next

## Components
* all passives are 0805 (~$1)
* 10MHz TCXO
  * [2.5 PPM 3.3V oscillator](https://www.mouser.com/ProductDetail/Fox/FOX924B-10000?qs=sGAEpiMZZMt8oz%2FHeiymAOqzUXC3weGFrHcwaz7vvYI%3D) ($2.35)
  * [0.2 PPM](https://www.mouser.com/ProductDetail/Murata-Electronics/XTCLH10M000THJA0P0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) alternative ($9.24)
  * [alt version](11.0592) for high framerates (2.5 PPM, 14.7456MHz)
* [SN74LV8154](https://www.mouser.com/ProductDetail/Texas-Instruments/SN74LV8154PWR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) ($0.99) TSSOP-20
* [FT230XS-R](https://www.mouser.com/ProductDetail/FTDI/FT230XS-R?qs=sGAEpiMZZMtv%252Bwxsgy%2FhiIaF6qCroMVR1i2pEQA5UpU%3D) ($2.04) SSOP-16
* [ATMega328](https://www.mouser.com/ProductDetail/Microchip-Technology-Atmel/ATMEGA328PB-AU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) ($1.38)
* [mini-USB jack](https://www.mouser.com/ProductDetail/CUI/UJ2-MBH-1-SMT-TR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) ($0.49)
* [SMA connector](https://www.mouser.com/ProductDetail/LPRS/SMA-CONNECTOR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) ($1.08)

Total is ~$10

## Changes for Rev2
* add pins to connect a SPI-driven 7-segment display like [this](https://www.amazon.com/dp/B07CL2YNJQ)
  * Make sure the MCU code is working for this first
  * You may be able to use PE0-3 (pins 3, 6, 19, and 22)
* make PCB smaller (there's lots of wasted space currently)
* add mounting screw holes
* R14 must be 0-Ohm!

### Notes after building

_see the front page_

Make the front-end like this. Make R3 50 Ohms.

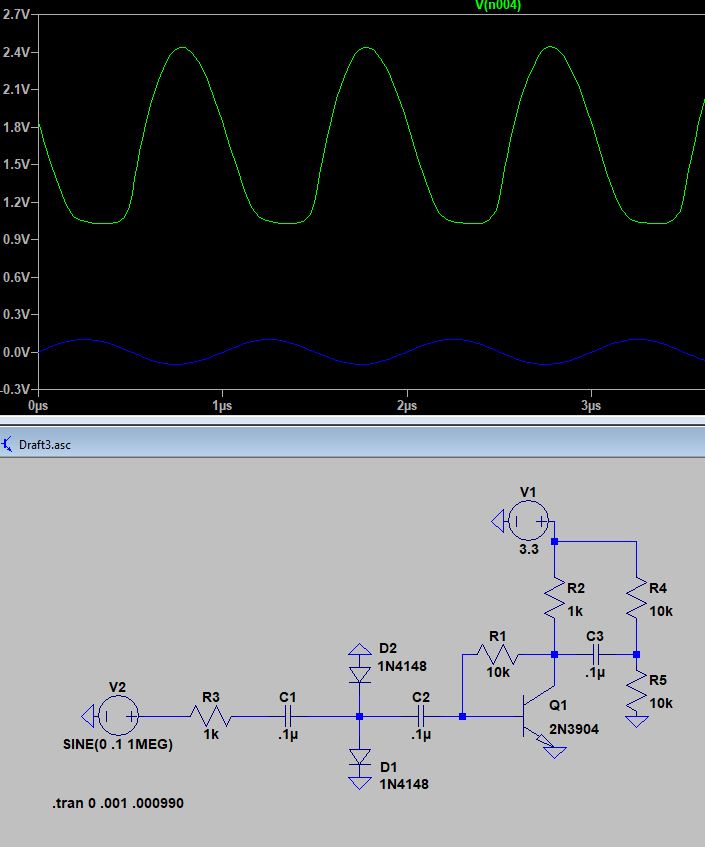
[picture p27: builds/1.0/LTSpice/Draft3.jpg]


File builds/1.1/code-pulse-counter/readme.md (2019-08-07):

# Alternative Code

This folder contains code for an alternative use of this device: a pulse counter with 100Hz update rate.

### Sample Output

The file [sample-output.csv](sample-output.csv) contains a lot of data to practice analyzing. It also demonstrates one counter rollover.

The output is 3 columns: time (in seconds, rolls over at 100), counter value (rolls over at 2^32), and "new pulses" (number since the last count). A new line is written every 10 milliseconds (100Hz). I couldn't reliably make it run faster. The timing is very accurate, down to 2.5PPM, defined by the TCXO. In these screenshots and sample data it's measuring a can oscillator near 28.7 MHz.

```
031.630,3404678919,0000286989
031.640,3404965908,0000286989
031.650,3405252898,0000286990
031.660,3405539891,0000286993
031.670,3405826876,0000286985
031.680,3406113871,0000286995
031.690,3406400860,0000286989
031.700,3406687850,0000286990
031.710,3406974840,0000286990
031.720,3407261827,0000286987
031.730,3407548820,0000286993
031.740,3407835807,0000286987
```

### RealTerm Setup: Text
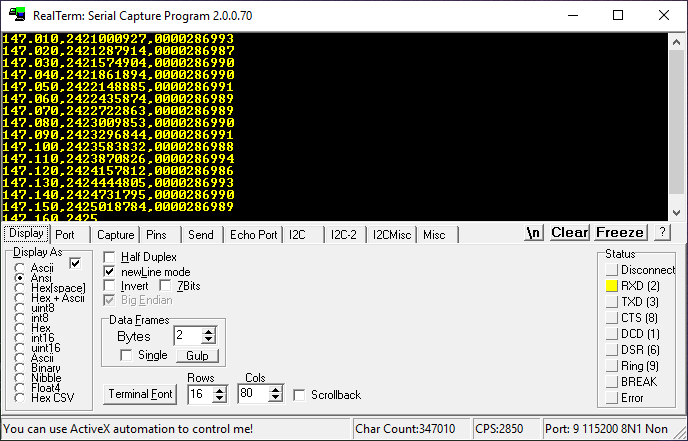
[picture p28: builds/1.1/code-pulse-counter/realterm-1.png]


### RealTerm Setup: Port
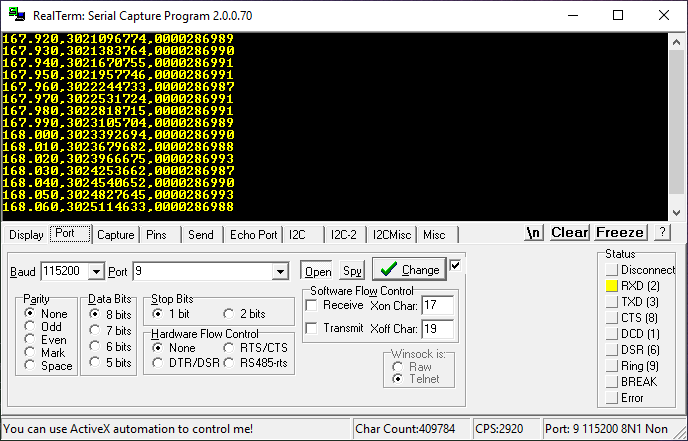
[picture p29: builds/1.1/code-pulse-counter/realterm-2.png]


### RealTerm Setup: CSV Output
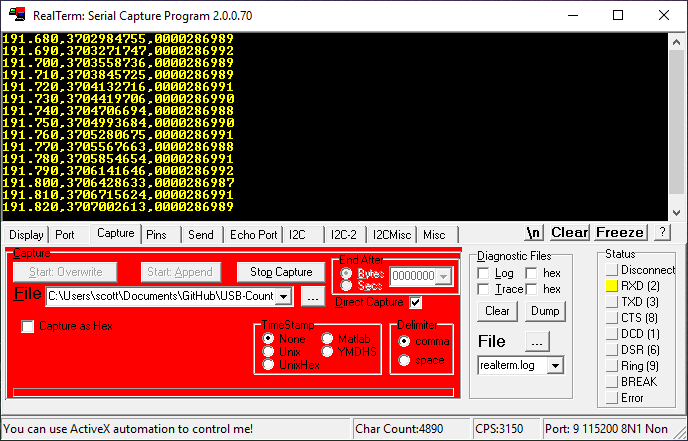
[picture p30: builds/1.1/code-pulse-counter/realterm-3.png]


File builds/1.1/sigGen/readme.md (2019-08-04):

# Test Signal Generator

It is useful to simulate pulses to practice counting them. A rev 1.0 counter board was repurposed to _produce_ signals.

Output is 48.83 kHz of 136 ns pulses. 

The counter can count 50MHz RF (20 ns period) so I suspect it can count pulses of much shorter duratioin.

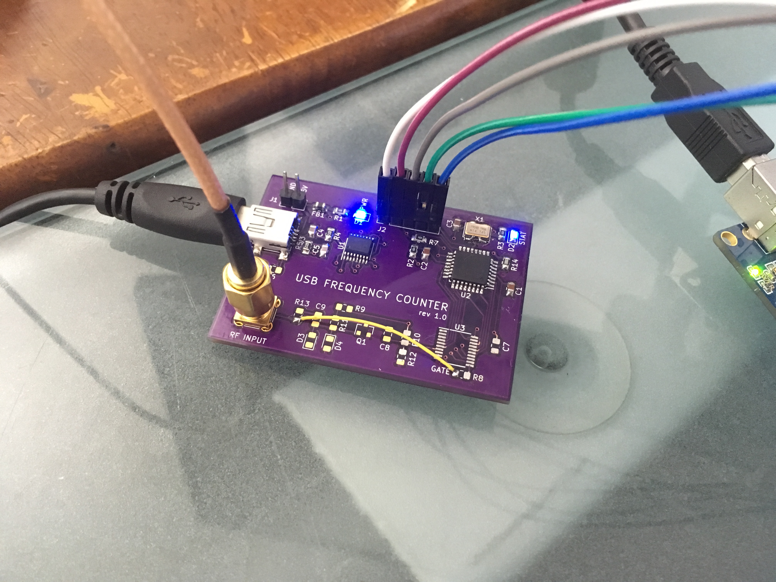
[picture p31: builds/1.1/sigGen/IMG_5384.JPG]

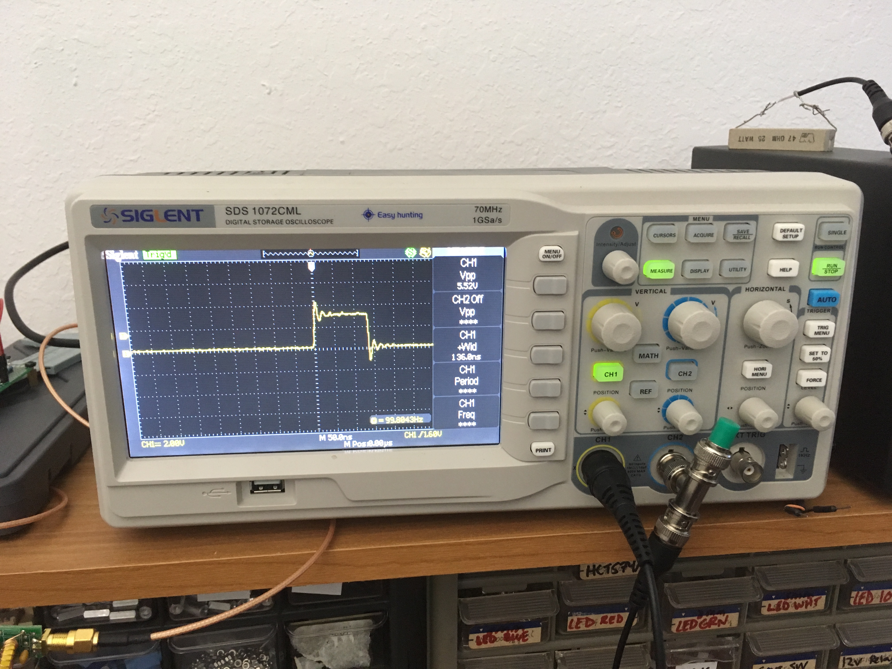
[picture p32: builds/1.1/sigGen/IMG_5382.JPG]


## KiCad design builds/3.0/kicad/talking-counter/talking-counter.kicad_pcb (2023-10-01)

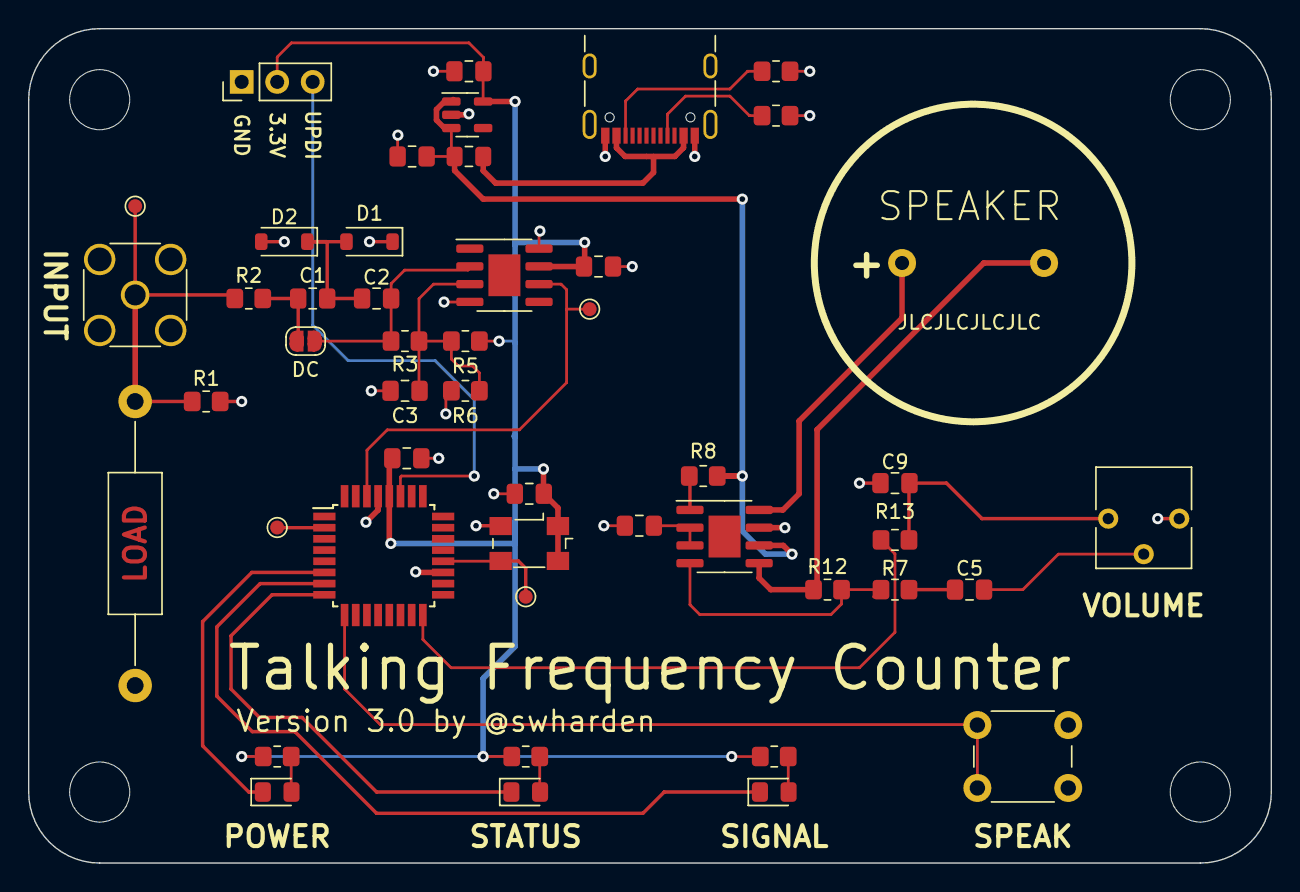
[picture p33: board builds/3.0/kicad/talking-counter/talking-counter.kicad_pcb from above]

Board: 2 copper layers, 88.9 x 59.7 mm, 48 parts (0 on the bottom side), 31 nets.

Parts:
C1, C2, C3, C4, C5, C6, C7, C8, C9, C10, C11: .1u; C_0805_2012Metric_Pad1.18x1.45mm_HandSolder
D1, D2: D; D_SOD-123
D3: SIGNAL; LED_0805_2012Metric_Pad1.15x1.40mm_HandSolder
D4: STATUS; LED_0805_2012Metric_Pad1.15x1.40mm_HandSolder
D6: POWER; LED_0805_2012Metric_Pad1.15x1.40mm_HandSolder
FB2: Ferrite; L_0805_2012Metric_Pad1.15x1.40mm_HandSolder
IC1: TLV3501AIDR; SOIC-8-1EP_3.9x4.9mm_P1.27mm_EP2.29x3mm
IC2: LM4862MX_NOPB; SOIC-8-1EP_3.9x4.9mm_P1.27mm_EP2.29x3mm
J1: Conn_Coaxial; SMA_Amphenol_132134_Vertical
J2: PROG; PinHeader_1x03_P2.54mm_Vertical
J3: USB_C_Receptacle_PowerOnly_6P; USB_C_Receptacle_GCT_USB4105-xx-A_16P_TopMnt_Horizontal
JP1: DC_INPUT; SolderJumper-2_P1.3mm_Open_RoundedPad1.0x1.5mm
LS1: Speaker; speaker SM231508
R1, R3: 100k; R_0805_2012Metric_Pad1.20x1.40mm_HandSolder
R2, R7: 1k; R_0805_2012Metric_Pad1.20x1.40mm_HandSolder
R4, R5, R6, R8, R9, R13, R16: 10k; R_0805_2012Metric_Pad1.20x1.40mm_HandSolder
R10, R11: 5.1k; R_0805_2012Metric_Pad1.20x1.40mm_HandSolder
R12: 47k; R_0805_2012Metric_Pad1.20x1.40mm_HandSolder
RV1: R_VOL; Potentiometer_Vishay_T73YP_Vertical
R_LOAD1: 50; R_Axial_DIN0411_L9.9mm_D3.6mm_P20.32mm_Horizontal
SW1: SPEAK; SW_PUSH_6mm_H5mm
TP1: AMP_OUT; TestPoint_Pad_D1.0mm
TP2: 10MHz; TestPoint_Pad_D1.0mm
TP3: SIG_IN; TestPoint_Pad_D1.0mm
TP4: MCU_TX; TestPoint_Pad_D1.0mm
U2: AP2112K-3.3; SOT-23-5
U3: AVR64DD32; TQFP-32_7x7mm_P0.8mm
U4: FT5HV; Oscillator_SMD_Fox_FT5H_5.0x3.2mm

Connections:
+3.3V: C4.2, C7.2, C8.2, C11.2, IC1.7 (V+), J2.2, R4.2, R5.2, R9.2, R16.2, U2.5 (VOUT), U3.28 (VDD), U4.1 (VC), U4.4 (VDD)
+5V: C10.2, FB2.2, IC2.6 (VDD), R8.1, U2.1 (VIN), U2.3 (EN)
COMP_OUT: IC1.6 (OUT), TP1.1, U3.30 (PA0)
DAC: C9.2, R13.2, RV1.1
GND: C3.2, C4.1, C6.2, C7.1, C8.1, C9.1, C10.1, C11.1, D1.1 (K), D2.2 (A), IC1.4 (V-), IC1.8 (SHDN), IC2.7 (GND), J1.2 (Ext), J2.1, J3.A1, J3.A12 (GND), R1.2, R6.1, R10.2, R11.2, RV1.3, R_LOAD1.2, SW1.1, SW1.2, U2.2 (GND), U3.19 (GND), U3.29 (GND), U4.2 (GND)
LED1: D6.1 (K), U3.6 (PC0)
LED2: D3.1 (K), U3.7 (PC1)
LED3: D4.1 (K), U3.8 (PC2)
unnamed: C5.1, R7.2
unnamed: C5.2, RV1.2
unnamed: C1.1, C2.2, D1.2 (A), D2.1 (K)
unnamed: D3.2 (A), R4.1
unnamed: D4.2 (A), R9.1
unnamed: D6.2 (A), R16.1
unnamed: FB2.1, J3.A4, J3.A9 (VBUS)
unnamed: C3.1, IC1.3 (+IN), R3.1, R5.1, R6.2
unnamed: C2.1, IC1.2 (-IN), JP1.2 (B), R3.2
unnamed: C6.1, IC2.2 (BYPASS), IC2.3 (+IN)
unnamed: IC2.4 (-IN), R7.1, R12.2
unnamed: IC2.1 (SHUTDOWN), R8.2
unnamed: IC2.5 (VO1), LS1.2, R12.1
unnamed: IC2.8 (VO2), LS1.1
unnamed: J1.1 (In), R1.1, R2.1, R_LOAD1.1, TP3.1
unnamed: J2.3, U3.27 (UPDI)
unnamed: J3.A5 (CC1), R11.1
unnamed: J3.B5 (CC2), R10.1
unnamed: C1.2, JP1.1 (A), R2.2
unnamed: TP4.1, U3.2 (PA4)
unnamed: SW1.1, SW1.2, U3.9 (PC3)
unnamed: R13.1, U3.16 (PD6)
unnamed: TP2.1, U3.20 (XTAL32K1/PF0), U4.3 (OUT)

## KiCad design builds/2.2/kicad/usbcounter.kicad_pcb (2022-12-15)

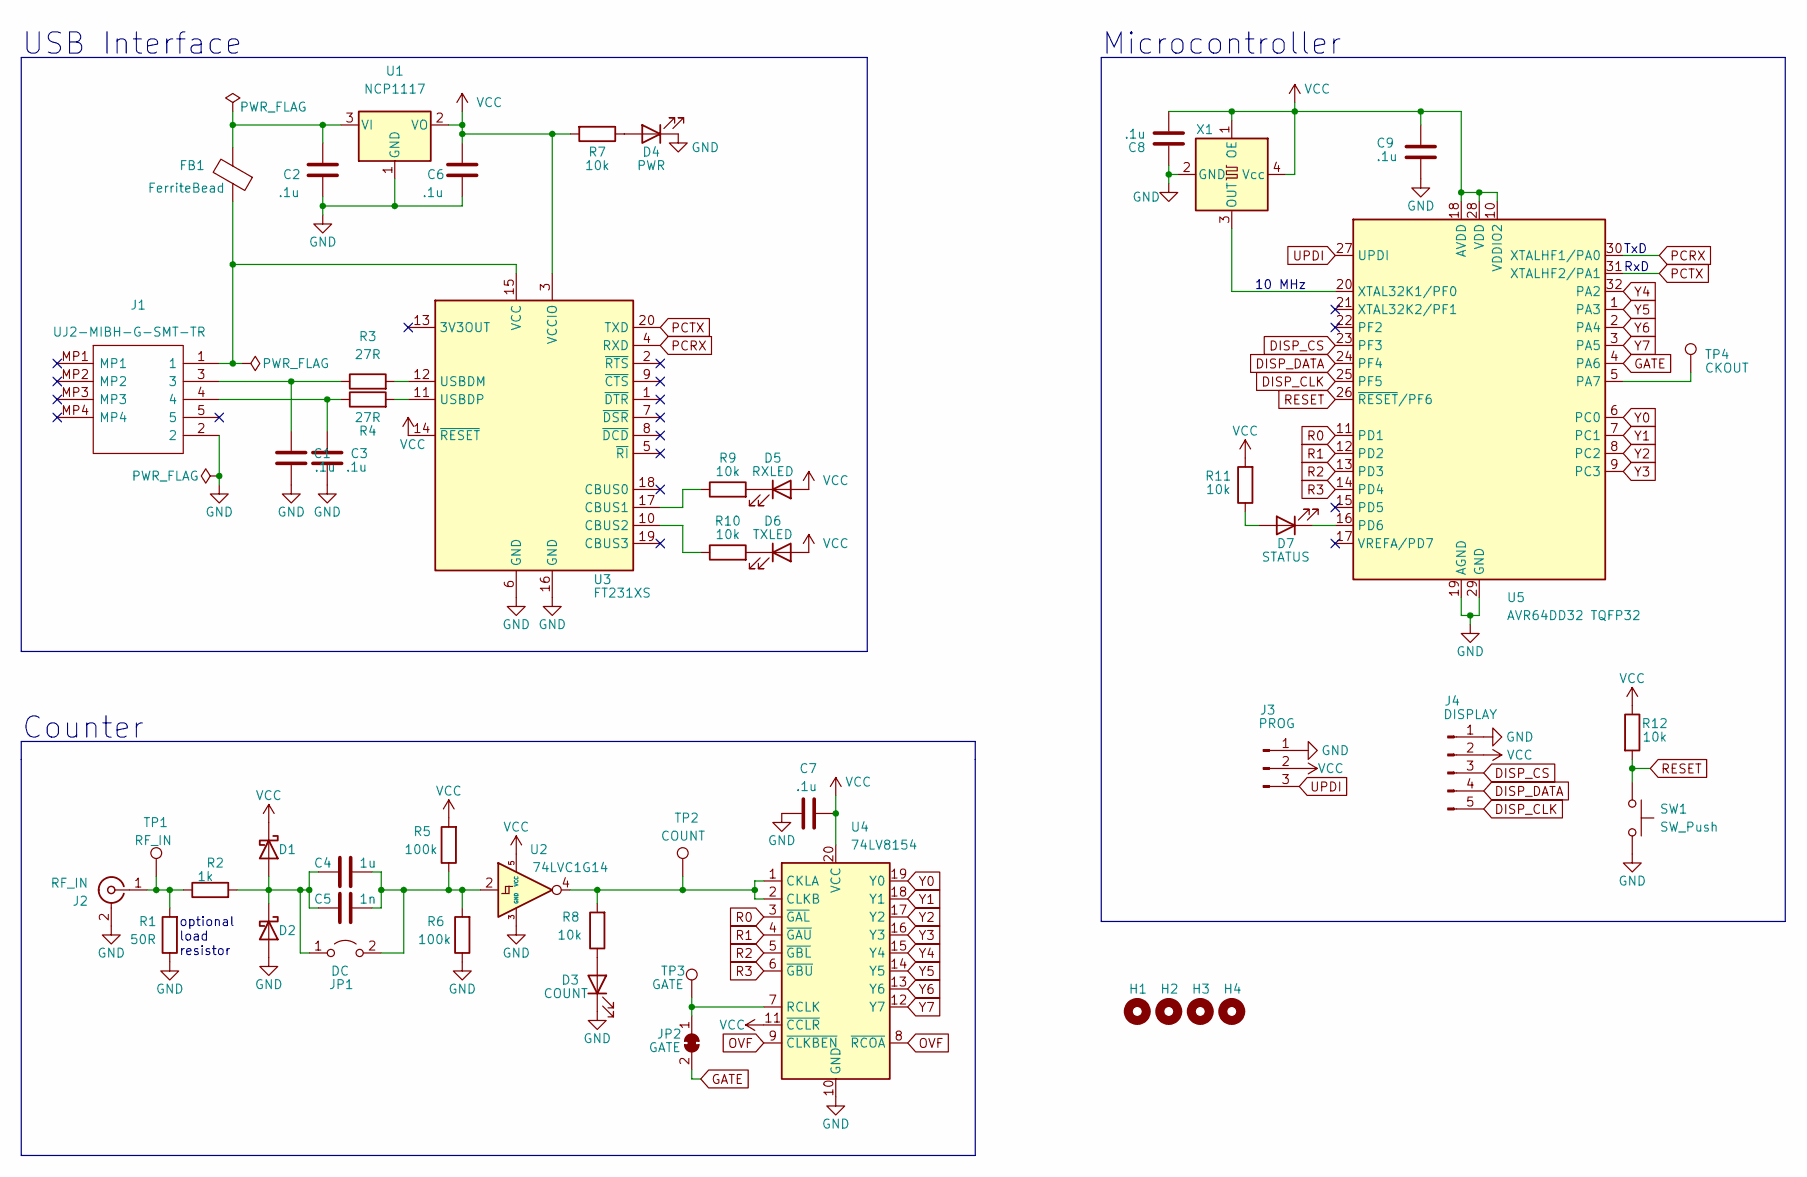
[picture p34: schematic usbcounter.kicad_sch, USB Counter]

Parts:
C1, C2, C3, C6, C7, C8, C9: .1u; C_0805_2012Metric_Pad1.18x1.45mm_HandSolder
C4: 1u; C_0805_2012Metric_Pad1.18x1.45mm_HandSolder
C5: 1n; C_0805_2012Metric_Pad1.18x1.45mm_HandSolder
D1, D2: D; LED_0805_2012Metric_Pad1.15x1.40mm_HandSolder
D3: COUNT; LED_0805_2012Metric_Pad1.15x1.40mm_HandSolder
D4: PWR; LED_0805_2012Metric_Pad1.15x1.40mm_HandSolder
D5: RXLED; LED_0805_2012Metric_Pad1.15x1.40mm_HandSolder
D6: TXLED; LED_0805_2012Metric_Pad1.15x1.40mm_HandSolder
D7: STATUS; LED_0805_2012Metric_Pad1.15x1.40mm_HandSolder
FB1: FerriteBead; L_0805_2012Metric_Pad1.15x1.40mm_HandSolder
H1, H2, H3, H4: MountingHole; MountingHole_4.3mm_M4_Pad
J1: UJ2-MIBH-G-SMT-TR; UJ2MIBHGSMTTR; Mouser Part Number 490-UJ2-MIBH-G-SMTTR
J2: RF_IN; SMA_Amphenol_901-144_Vertical
J3: PROG; PinHeader_1x03_P2.54mm_Vertical
J4: DISPLAY; PinHeader_1x05_P2.54mm_Vertical
JP1: DC; SolderJumper-2_P1.3mm_Open_RoundedPad1.0x1.5mm
JP2: GATE; SolderJumper-2_P1.3mm_Bridged_RoundedPad1.0x1.5mm
R1: 50R; R_Axial_DIN0207_L6.3mm_D2.5mm_P7.62mm_Horizontal
R2: 1k; R_0805_2012Metric_Pad1.20x1.40mm_HandSolder
R3, R4: 27R; R_0805_2012Metric_Pad1.20x1.40mm_HandSolder
R5, R6: 100k; R_0805_2012Metric_Pad1.20x1.40mm_HandSolder
R7, R8, R9, R10, R11, R12: 10k; R_0805_2012Metric_Pad1.20x1.40mm_HandSolder
SW1: SW_Push; SW_SPST_TL3342
TP1: RF_IN; TestPoint_Pad_D2.0mm
TP2: COUNT; TestPoint_Pad_D2.0mm
TP3: GATE; TestPoint_Pad_D2.0mm
TP4: CKOUT; TestPoint_Pad_D2.0mm
U1: NCP1117; SOT-223-3_TabPin2
U2: 74LVC1G14; SOT-23-5
U3: FT231XS; SSOP-20_3.9x8.7mm_P0.635mm
U4: 74LV8154; TSSOP-20_4.4x6.5mm_P0.65mm
U5: AVR64DD32 TQFP32; TQFP-32_7x7mm_P0.8mm
X1: TCXO; Oscillator_SMD_SeikoEpson_SG8002CE-4Pin_3.2x2.5mm

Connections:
DISP_CLK: J4.5, U5.25 (PF5)
DISP_CS: J4.3, U5.23 (PF3)
DISP_DATA: J4.4, U5.24 (PF4)
GATE: JP2.2 (B), U5.4 (PA6)
GND: C1.1, C2.1, C3.1, C6.1, C7.1, C8.2, C9.1, D2.2 (A), D3.1 (K), D4.1 (K), J1.2, J2.2 (Ext), J3.1, J4.1, R1.1, R6.1, SW1.2, U1.1 (GND), U2.3 (GND), U3.6 (GND), U3.16 (GND), U4.10 (GND), U5.19 (AGND), U5.29 (GND), X1.2 (GND)
unnamed: C1.2, J1.3, R3.1
unnamed: C2.2, FB1.2, U1.3 (VI)
unnamed: C3.2, J1.4, R4.1
unnamed: C4.1, C5.1, D1.2 (A), D2.1 (K), JP1.1 (A), R2.2
unnamed: C4.2, C5.2, JP1.2 (B), R5.1, R6.2, U2.2
unnamed: D3.2 (A), R8.1
unnamed: D4.2 (A), R7.1
unnamed: D5.1 (K), R9.2
unnamed: D6.1 (K), R10.2
unnamed: FB1.1, J1.1, U3.15 (VCC)
unnamed: J2.1 (In), R1.2, R2.1, TP1.1
unnamed: JP2.1 (A), TP3.1, U4.7 (RCLK)
unnamed: R3.2, U3.12 (USBDM)
unnamed: R4.2, U3.11 (USBDP)
unnamed: R8.2, TP2.1, U2.4, U4.1 (CKLA), U4.2 (CLKB)
unnamed: R9.1, U3.17 (CBUS1)
unnamed: R10.1, U3.10 (CBUS2)
unnamed: D7.2 (A), R11.1
unnamed: TP4.1, U5.5 (PA7)
unnamed: D7.1 (K), U5.16 (PD6)
unnamed: U5.20 (XTAL32K1/PF0), X1.3 (OUT)
OVF: U4.8 (~RCOA), U4.9 (~CLKBEN)
PCRX: U3.4 (RXD), U5.30 (XTALHF1/PA0)
PCTX: U3.20 (TXD), U5.31 (XTALHF2/PA1)
R0: U4.3 (~GAL), U5.11 (PD1)
R1: U4.4 (~GAU), U5.12 (PD2)
R2: U4.5 (~GBL), U5.13 (PD3)
R3: U4.6 (~GBU), U5.14 (PD4)
RESET: R12.2, SW1.1, U5.26 (~RESET/PF6)
UPDI: J3.3, U5.27 (UPDI)
VCC: C6.2, C7.2, C8.1, C9.2, D1.1 (K), D5.2 (A), D6.2 (A), J3.2, J4.2, R5.2, R7.2, R11.2, R12.1, U1.2 (VO), U2.5 (VCC), U3.3 (VCCIO), U3.14 (~RESET), U4.11 (~CCLR), U4.20 (VCC), U5.10 (VDDIO2), U5.18 (AVDD), U5.28 (VDD), X1.1 (OE), X1.4 (Vcc)
Y0: U4.19 (Y0), U5.6 (PC0)
Y1: U4.18 (Y1), U5.7 (PC1)
Y2: U4.17 (Y2), U5.8 (PC2)
Y3: U4.16 (Y3), U5.9 (PC3)
Y4: U4.15 (Y4), U5.32 (PA2)
Y5: U4.14 (Y5), U5.1 (PA3)
Y6: U4.13 (Y6), U5.2 (PA4)
Y7: U4.12 (Y7), U5.3 (PA5)

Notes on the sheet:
USB Interface
TxD
10 MHz
Microcontroller
RxD
Counter
optional load resistor

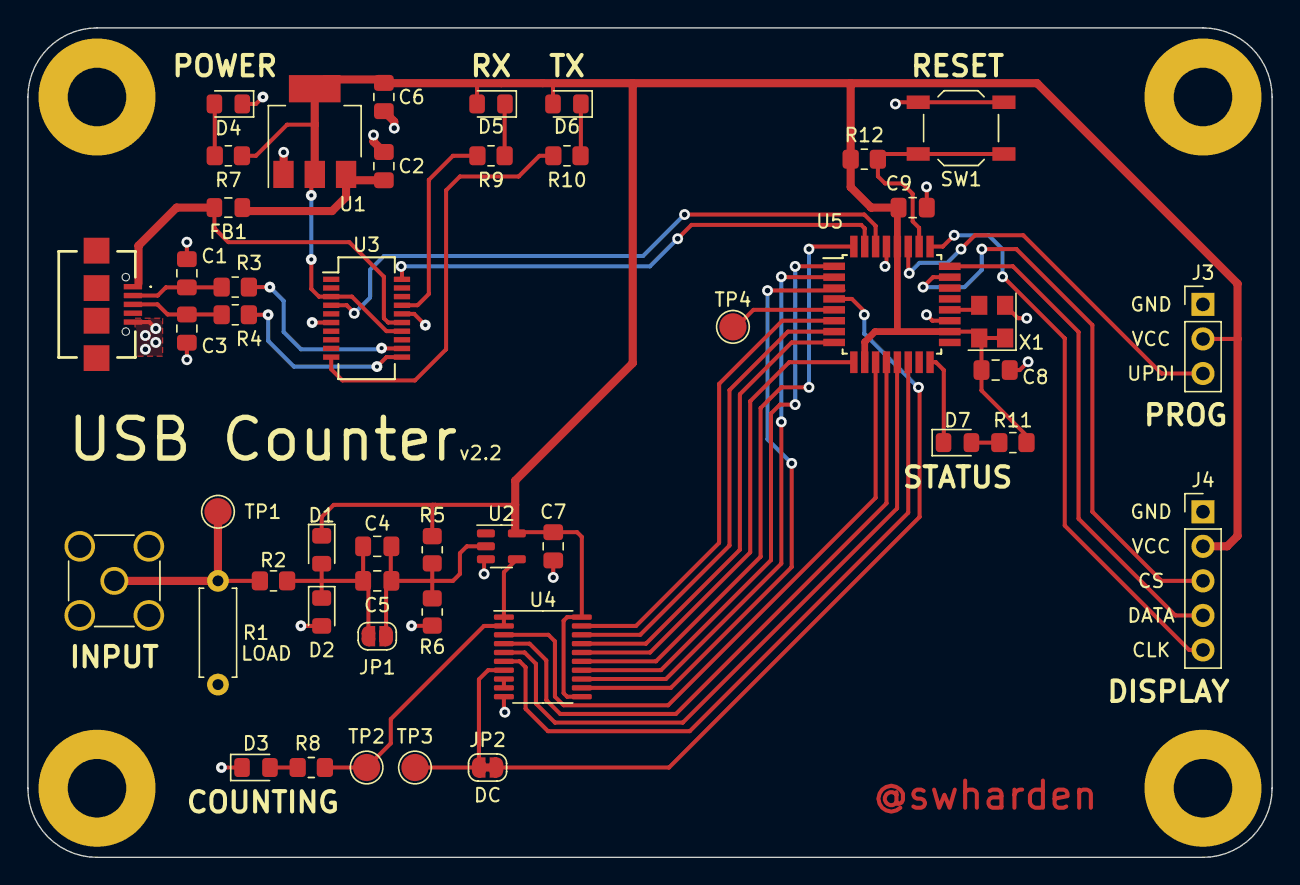
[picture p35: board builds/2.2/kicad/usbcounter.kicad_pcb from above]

Board: 2 copper layers, 91.4 x 61.0 mm, 50 parts (0 on the bottom side), 44 nets.

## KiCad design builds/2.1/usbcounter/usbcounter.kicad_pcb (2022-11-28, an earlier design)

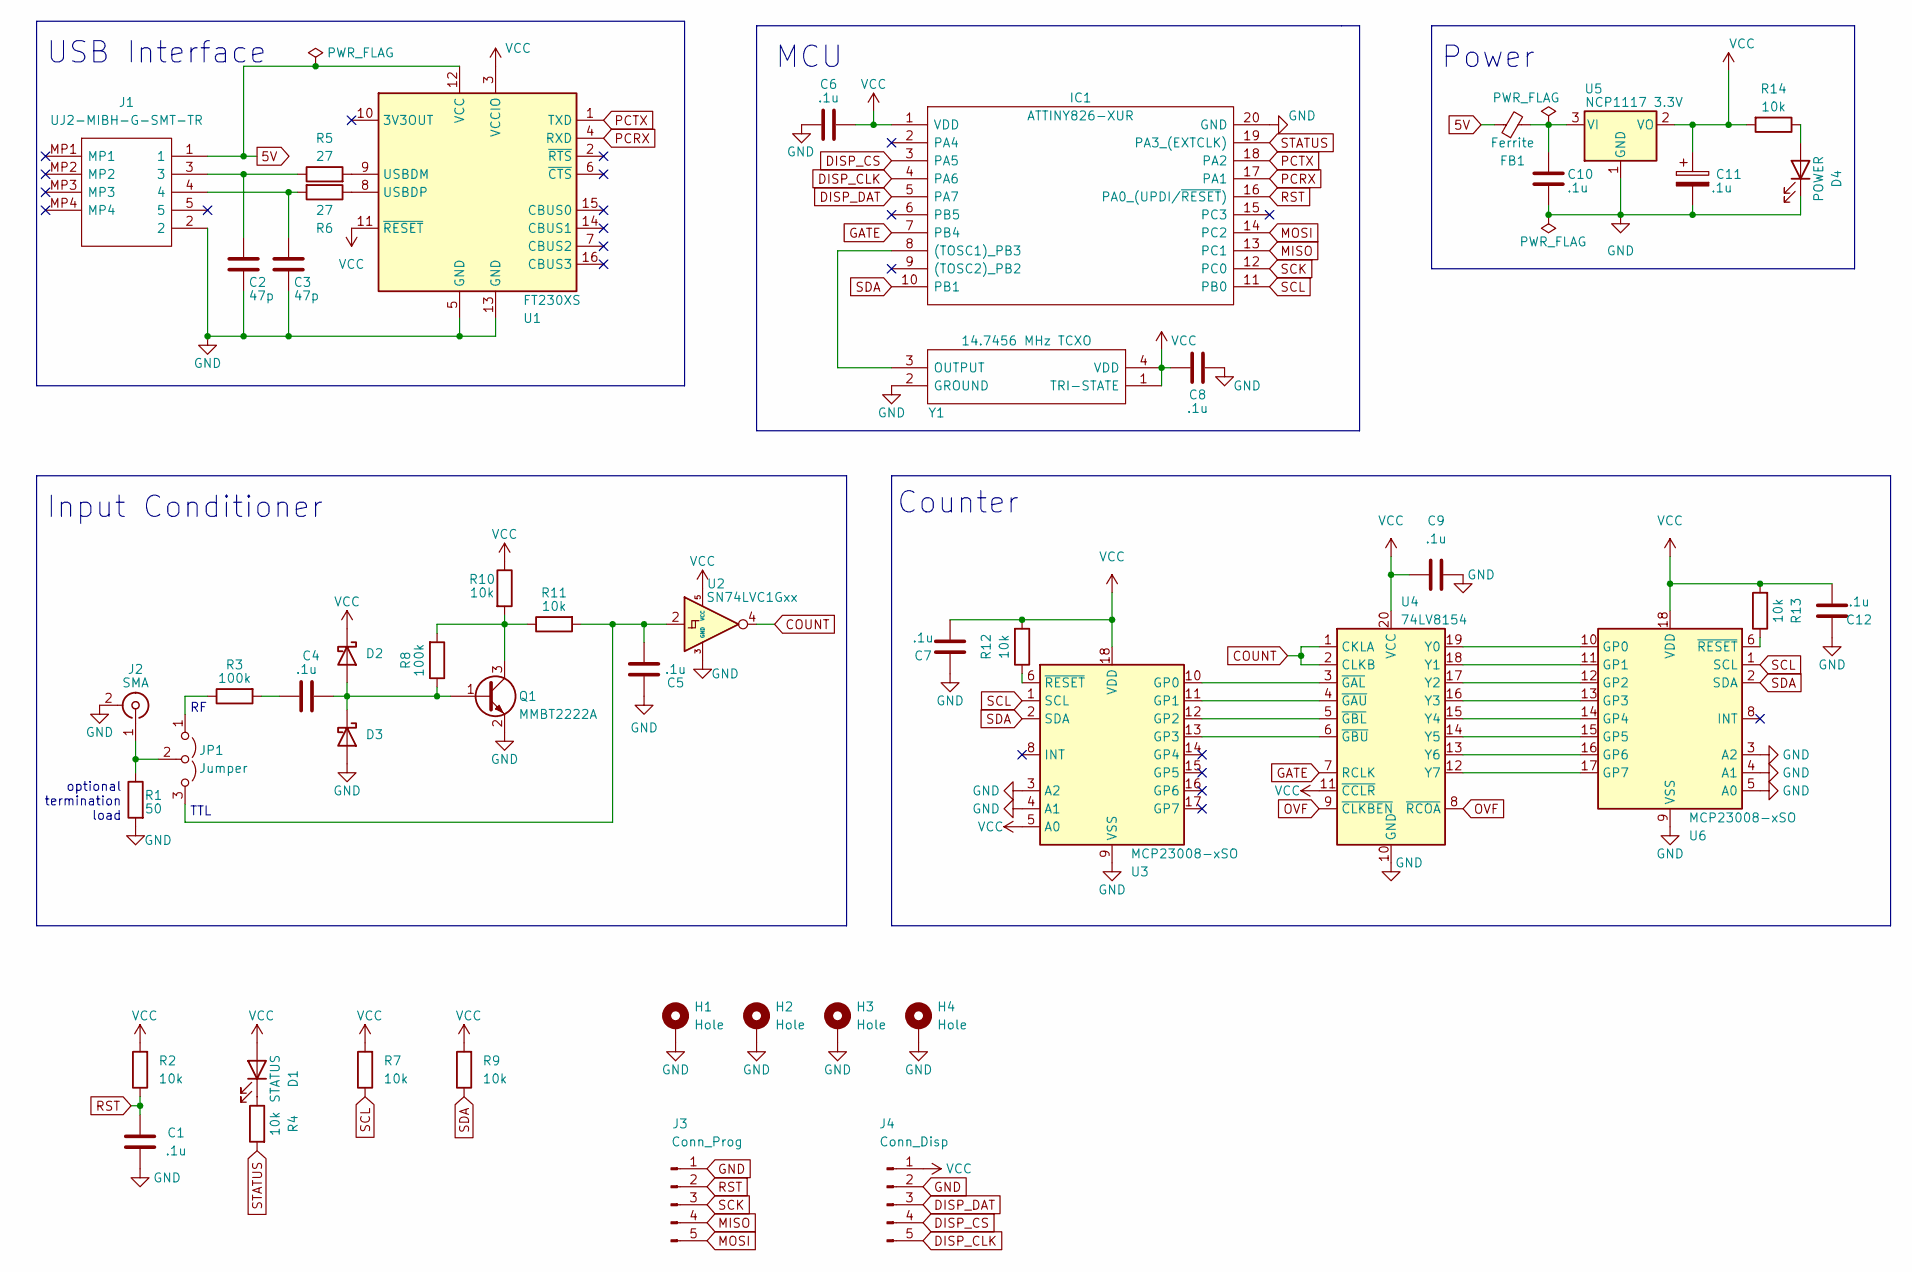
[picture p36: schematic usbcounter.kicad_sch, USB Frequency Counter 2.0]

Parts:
C1, C4, C5, C6, C7, C8, C9, C10, C12: .1u; C_0805_2012Metric_Pad1.18x1.45mm_HandSolder
C2, C3: 47p; C_0805_2012Metric_Pad1.18x1.45mm_HandSolder
C11: .1u; CP_EIA-2012-15_AVX-P_Pad1.30x1.05mm_HandSolder
D1: STATUS; LED_0805_2012Metric_Pad1.15x1.40mm_HandSolder
D2, D3: D; D_SOD-323_HandSoldering
D4: POWER; LED_0805_2012Metric_Pad1.15x1.40mm_HandSolder
FB1: Ferrite; L_0805_2012Metric_Pad1.15x1.40mm_HandSolder
H1, H2, H3, H4: Hole; MountingHole_2.2mm_M2_DIN965_Pad
IC1: ATTINY826-XUR; SOP65P780X200-20N; Mouser Part Number 579-ATTINY826-XUR
J1: UJ2-MIBH-G-SMT-TR; UJ2MIBHGSMTTR; Mouser Part Number 490-UJ2-MIBH-G-SMTTR
J2: SMA; SMA_Amphenol_901-144_Vertical
J3: Conn_Prog; PinHeader_1x05_P2.54mm_Vertical
J4: Conn_Disp; PinHeader_1x05_P2.54mm_Vertical
JP1: Jumper; PinHeader_1x03_P2.54mm_Vertical
Q1: MMBT2222A; SOT-23
R1: 50; R_Axial_DIN0207_L6.3mm_D2.5mm_P10.16mm_Horizontal
R2, R4, R7, R9, R10, R11, R12, R13, R14: 10k; R_0805_2012Metric_Pad1.20x1.40mm_HandSolder
R3, R8: 100k; R_0805_2012Metric_Pad1.20x1.40mm_HandSolder
R5, R6: 27; R_0805_2012Metric_Pad1.20x1.40mm_HandSolder
U1: FT230XS; SSOP-16_3.9x4.9mm_P0.635mm
U2: SN74LVC1Gxx; SOT-23-5
U3, U6: MCP23008-xSO; SOIC-18W_7.5x11.6mm_P1.27mm
U4: 74LV8154; TSSOP-20_4.4x6.5mm_P0.65mm
U5: NCP1117 3.3V; SOT-223-3_TabPin2
Y1: 14.7456 MHz TCXO; ECSTXO3225MV1474TR; Mouser Part Number 520-TXO-3225MV-1474T

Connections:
5V: FB1.1, J1.1, U1.12 (VCC)
COUNT: U2.4, U4.1 (CKLA), U4.2 (CLKB)
DISP_CLK: IC1.4 (PA6), J4.5
DISP_CS: IC1.3 (PA5), J4.4
DISP_DAT: IC1.5 (PA7), J4.3
GATE: IC1.7 (PB4), U4.7 (RCLK)
GND: C1.2, C2.1, C3.1, C5.1, C6.2, C7.1, C8.1, C9.1, C10.2, C11.2, C12.1, D3.2 (A), D4.1 (K), H1.1, H2.1, H3.1, H4.1, IC1.20 (GND), J1.2, J2.2 (Ext), J3.1, J4.2, Q1.2 (E), R1.2, U1.5 (GND), U1.13 (GND), U2.3 (GND), U3.3 (A2), U3.4 (A1), U3.9 (VSS), U4.10 (GND), U5.1 (GND), U6.3 (A2), U6.4 (A1), U6.5 (A0), U6.9 (VSS), Y1.2 (GROUND)
MISO: IC1.13 (PC1), J3.4
MOSI: IC1.14 (PC2), J3.5
unnamed: C2.2, J1.3, R5.1
unnamed: C3.2, J1.4, R6.2
unnamed: C4.1, D2.2 (A), D3.1 (K), Q1.1 (B), R8.1
unnamed: C4.2, R3.2
unnamed: C5.2, JP1.3 (B), R11.2, U2.2
unnamed: C10.1, FB1.2, U5.3 (VI)
unnamed: D1.1 (K), R4.1
unnamed: D4.2 (A), R14.1
unnamed: IC1.8 ((TOSC1)_PB3), Y1.3 (OUTPUT)
unnamed: J2.1 (In), JP1.2 (C), R1.1
unnamed: JP1.1 (A), R3.1
unnamed: Q1.3 (C), R8.2, R10.2, R11.1
unnamed: R5.2, U1.9 (USBDM)
unnamed: R6.1, U1.8 (USBDP)
unnamed: R12.1, U3.6 (~RESET)
unnamed: R13.1, U6.6 (~RESET)
unnamed: U3.10 (GP0), U4.3 (~GAL)
unnamed: U3.11 (GP1), U4.4 (~GAU)
unnamed: U3.12 (GP2), U4.5 (~GBL)
unnamed: U3.13 (GP3), U4.6 (~GBU)
unnamed: U4.12 (Y7), U6.17 (GP7)
unnamed: U4.13 (Y6), U6.16 (GP6)
unnamed: U4.14 (Y5), U6.15 (GP5)
unnamed: U4.15 (Y4), U6.14 (GP4)
unnamed: U4.16 (Y3), U6.13 (GP3)
unnamed: U4.17 (Y2), U6.12 (GP2)
unnamed: U4.18 (Y1), U6.11 (GP1)
unnamed: U4.19 (Y0), U6.10 (GP0)
OVF: U4.8 (~RCOA), U4.9 (~CLKBEN)
PCRX: IC1.17 (PA1), U1.4 (RXD)
PCTX: IC1.18 (PA2), U1.1 (TXD)
RST: C1.1, IC1.16 (PA0_(UPDI/~RESET)), J3.2, R2.1
SCK: IC1.12 (PC0), J3.3
SCL: IC1.11 (PB0), R7.1, U3.1 (SCL), U6.1 (SCL)
SDA: IC1.10 (PB1), R9.1, U3.2 (SDA), U6.2 (SDA)
STATUS: IC1.19 (PA3_(EXTCLK)), R4.2
VCC: C6.1, C7.2, C8.2, C9.2, C11.1, C12.2, D1.2 (A), D2.1 (K), IC1.1 (VDD), J4.1, R2.2, R7.2, R9.2, R10.1, R12.2, R13.2, R14.2, U1.3 (VCCIO), U1.11 (~RESET), U2.5 (VCC), U3.5 (A0), U3.18 (VDD), U4.11 (~CCLR), U4.20 (VCC), U5.2 (VO), U6.18 (VDD), Y1.1 (TRI-STATE), Y1.4 (VDD)

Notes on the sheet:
USB Interface
MCU
Input Conditioner
Power
Counter
TTL
optional termination load

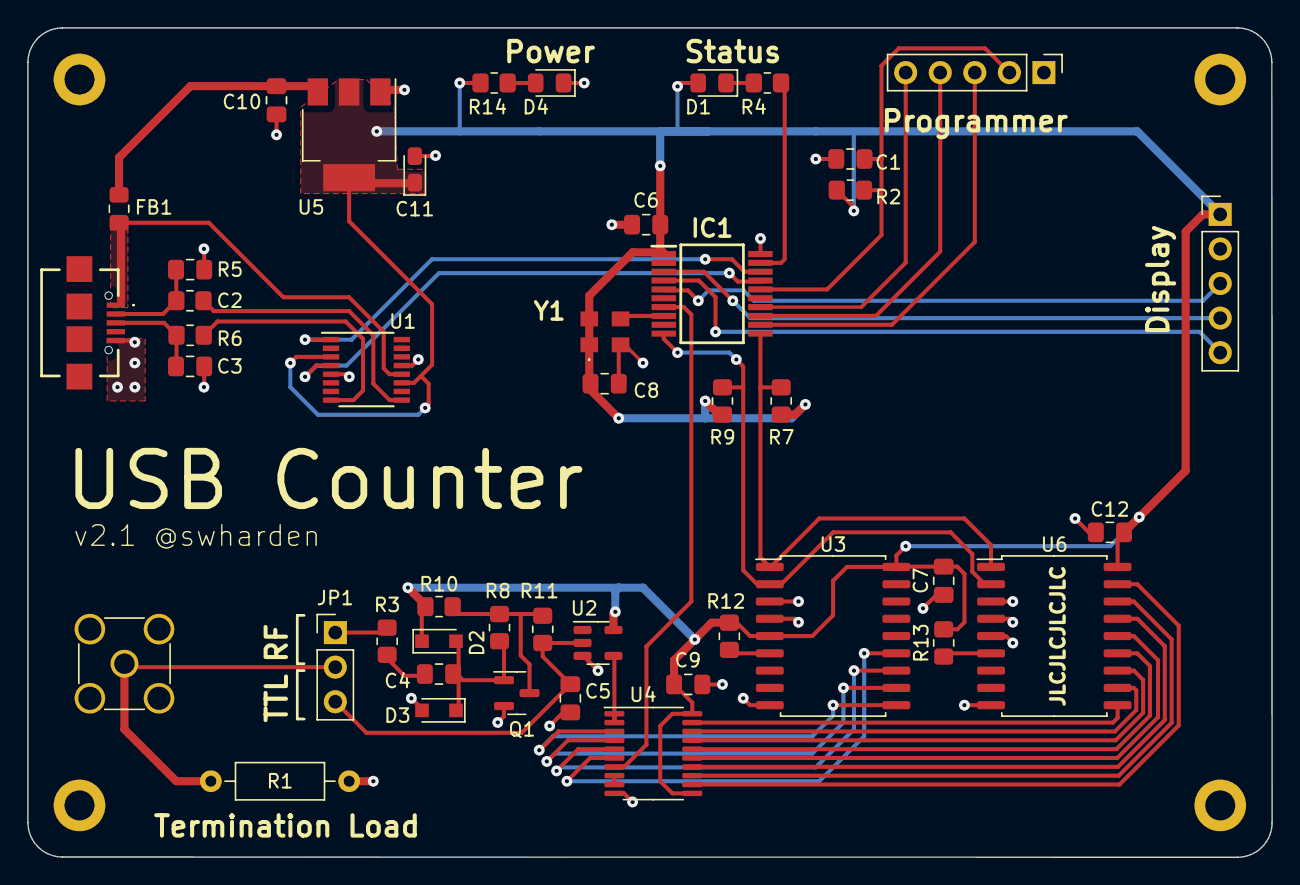
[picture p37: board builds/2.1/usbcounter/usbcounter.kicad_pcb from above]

Board: 2 copper layers, 91.4 x 60.9 mm, 49 parts (0 on the bottom side), 46 nets.

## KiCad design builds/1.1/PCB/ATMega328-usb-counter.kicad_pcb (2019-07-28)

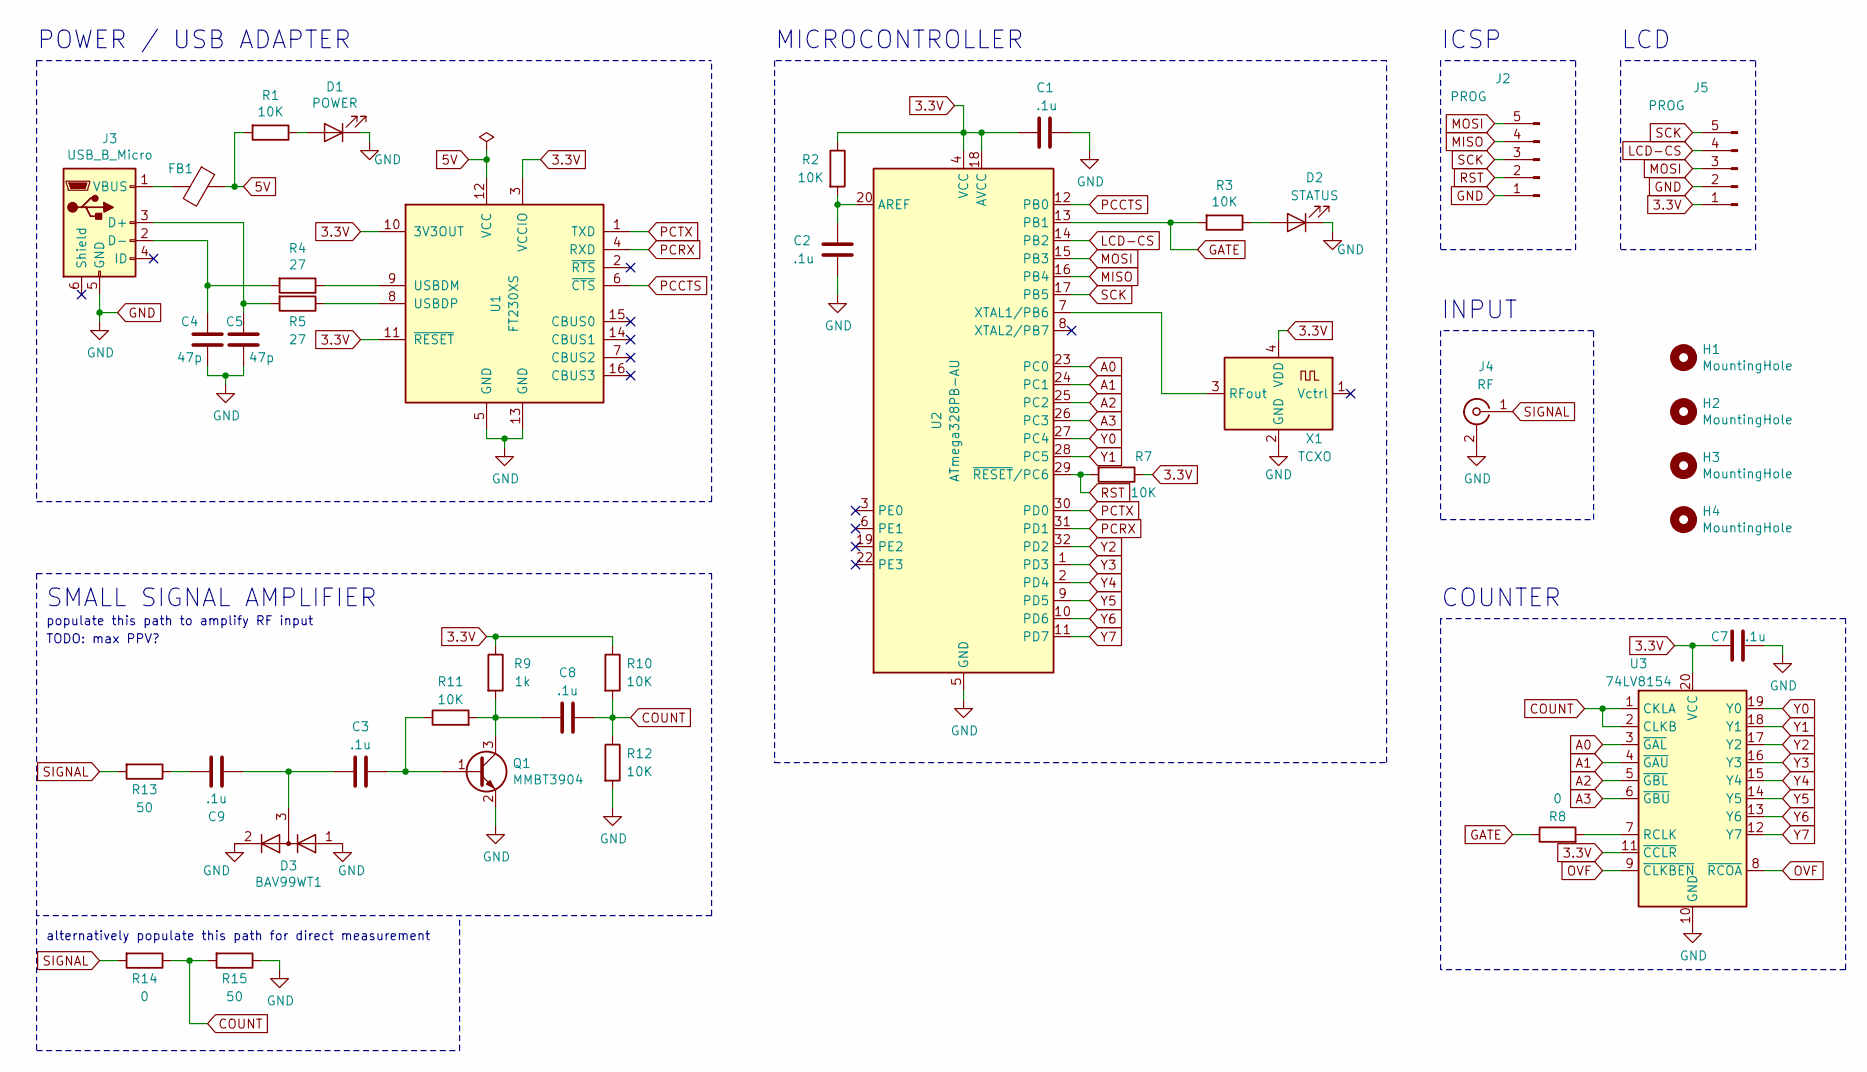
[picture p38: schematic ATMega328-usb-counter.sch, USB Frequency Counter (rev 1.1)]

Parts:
C1, C2, C3, C7, C8, C9: .1u; C_0805_2012Metric_Pad1.15x1.40mm_HandSolder
C4, C5: 47p; C_0805_2012Metric_Pad1.15x1.40mm_HandSolder
D1: POWER; LED_0805_2012Metric_Pad1.15x1.40mm_HandSolder
D2: STATUS; LED_0805_2012Metric_Pad1.15x1.40mm_HandSolder
D3: BAV99WT1; SOT-323_SC-70_Handsoldering
FB1: Ferrite; R_0805_2012Metric_Pad1.15x1.40mm_HandSolder
H1, H2, H3, H4: MountingHole; MountingHole_4.3mm_M4_Pad_Via
J2, J5: PROG; PinHeader_1x05_P2.54mm_Vertical
J3: USB_B_Micro; USB_Micro-B_Molex-105017-0001
J4: RF; SMA_Amphenol_901-144_Vertical
Q1: MMBT3904; SOT-23
R1, R2, R3, R7, R10, R11, R12: 10K; R_0805_2012Metric_Pad1.15x1.40mm_HandSolder
R4, R5: 27; R_0805_2012Metric_Pad1.15x1.40mm_HandSolder
R8, R14: 0; R_0805_2012Metric_Pad1.15x1.40mm_HandSolder
R9: 1k; R_0805_2012Metric_Pad1.15x1.40mm_HandSolder
R13, R15: 50; R_0805_2012Metric_Pad1.15x1.40mm_HandSolder
U1: FT230XS; SSOP-16_3.9x4.9mm_P0.635mm
U2: ATmega328PB-AU; TQFP-32_7x7mm_P0.8mm
U3: 74LV8154; TSSOP-20_4.4x6.5mm_P0.65mm
X1: TCXO; Oscillator_SMD_TXC_7C-4Pin_5.0x3.2mm_HandSoldering

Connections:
3.3V: C1.1, C7.1, J5.1, R2.1, R7.1, R9.1, R10.1, U1.3 (VCCIO), U1.10 (3V3OUT), U1.11 (~RESET), U2.4 (VCC), U2.18 (AVCC), U3.11 (~CCLR), U3.20 (VCC), X1.4 (VDD); also elsewhere on the board
5V: FB1.1, R1.2, U1.12 (VCC)
A0: U2.23 (PC0), U3.3 (~GAL)
A1: U2.24 (PC1), U3.4 (~GAU)
A2: U2.25 (PC2), U3.5 (~GBL)
A3: U2.26 (PC3), U3.6 (~GBU)
COUNT: C8.1, R10.2, R12.1, R14.1, R15.2, U3.1 (CKLA), U3.2 (CLKB)
GATE: R3.2, R8.1, U2.13 (PB1)
GND: C1.2, C2.1, C4.1, C5.1, C7.2, D1.1 (K), D2.1 (K), D3.1 (A), D3.2 (K), J2.1, J3.5 (GND), J4.2 (Ext), J5.2, Q1.2 (E), R12.2, R15.1, U1.5 (GND), U1.13 (GND), U2.5 (GND), U2.21 (GND), U3.10 (GND), X1.2 (GND); also elsewhere on the board
LCD-CS: J5.4, U2.14 (PB2)
MISO: J2.4, U2.16 (PB4)
MOSI: J2.5, J5.3, U2.15 (PB3)
unnamed: C2.2, R2.2, U2.20 (AREF)
unnamed: C3.1, Q1.1 (B), R11.1
unnamed: C3.2, C9.2, D3.3 (common)
unnamed: C4.2, J3.2 (D-), R4.2
unnamed: C5.2, J3.3 (D+), R5.2
unnamed: C8.2, Q1.3 (C), R9.2, R11.2
unnamed: C9.1, R13.1
unnamed: D1.2 (A), R1.1
unnamed: D2.2 (A), R3.1
unnamed: FB1.2, J3.1 (VBUS)
unnamed: R4.1, U1.9 (USBDM)
unnamed: R5.1, U1.8 (USBDP)
unnamed: R8.2, U3.7 (RCLK)
unnamed 26: U2.7 (XTAL1/PB6), X1.3 (RFout); also elsewhere on the board
OVF: U3.8 (~RCOA), U3.9 (~CLKBEN)
PCCTS: U1.6 (~CTS), U2.12 (PB0)
PCRX: U1.4 (RXD), U2.31 (PD1)
PCTX: U1.1 (TXD), U2.30 (PD0)
RST: J2.2, R7.2, U2.29 (~RESET~/PC6)
SCK: J2.3, J5.5, U2.17 (PB5)
SIGNAL: J4.1 (In), R13.2, R14.2
Y0: U2.27 (PC4), U3.19 (Y0)
Y1: U2.28 (PC5), U3.18 (Y1)
Y2: U2.32 (PD2), U3.17 (Y2)
Y3: U2.1 (PD3), U3.16 (Y3)
Y4: U2.2 (PD4), U3.15 (Y4)
Y5: U2.9 (PD5), U3.14 (Y5)
Y6: U2.10 (PD6), U3.13 (Y6)
Y7: U2.11 (PD7), U3.12 (Y7)

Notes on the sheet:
POWER / USB ADAPTER
MICROCONTROLLER
ICSP
SMALL SIGNAL AMPLIFIER
TODO: max PPV?
alternatively populate this path for direct measurement
populate this path to amplify RF input
COUNTER
INPUT
LCD

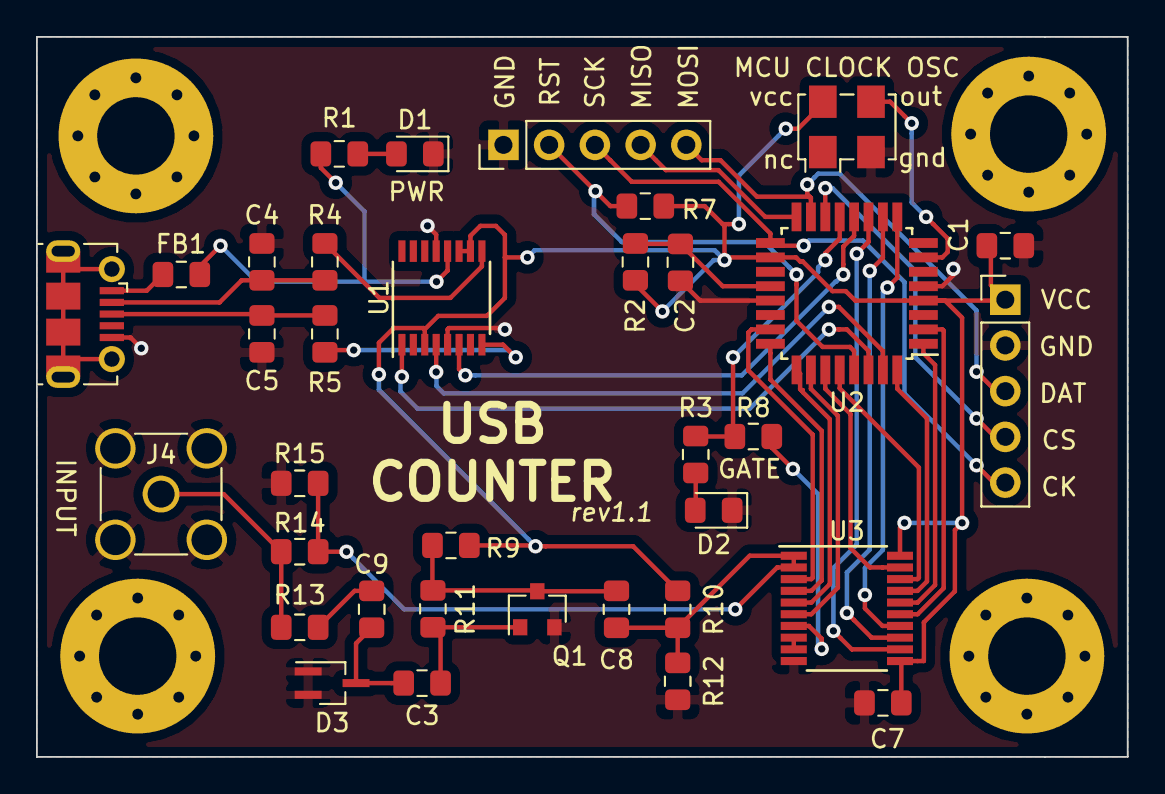
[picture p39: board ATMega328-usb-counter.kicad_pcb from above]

Board: 2 copper layers, 60.6 x 40.0 mm, 39 parts (0 on the bottom side), 41 nets.

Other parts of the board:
MCU CLOCK OSC: TCXO; Oscillator_SMD_TXC_7C-4Pin_5.0x3.2mm_HandSoldering

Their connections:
3.3V: MCU CLOCK OSC.4; also elsewhere on the board
GND: MCU CLOCK OSC.2; also elsewhere on the board
unnamed 26: MCU CLOCK OSC.3; also elsewhere on the board

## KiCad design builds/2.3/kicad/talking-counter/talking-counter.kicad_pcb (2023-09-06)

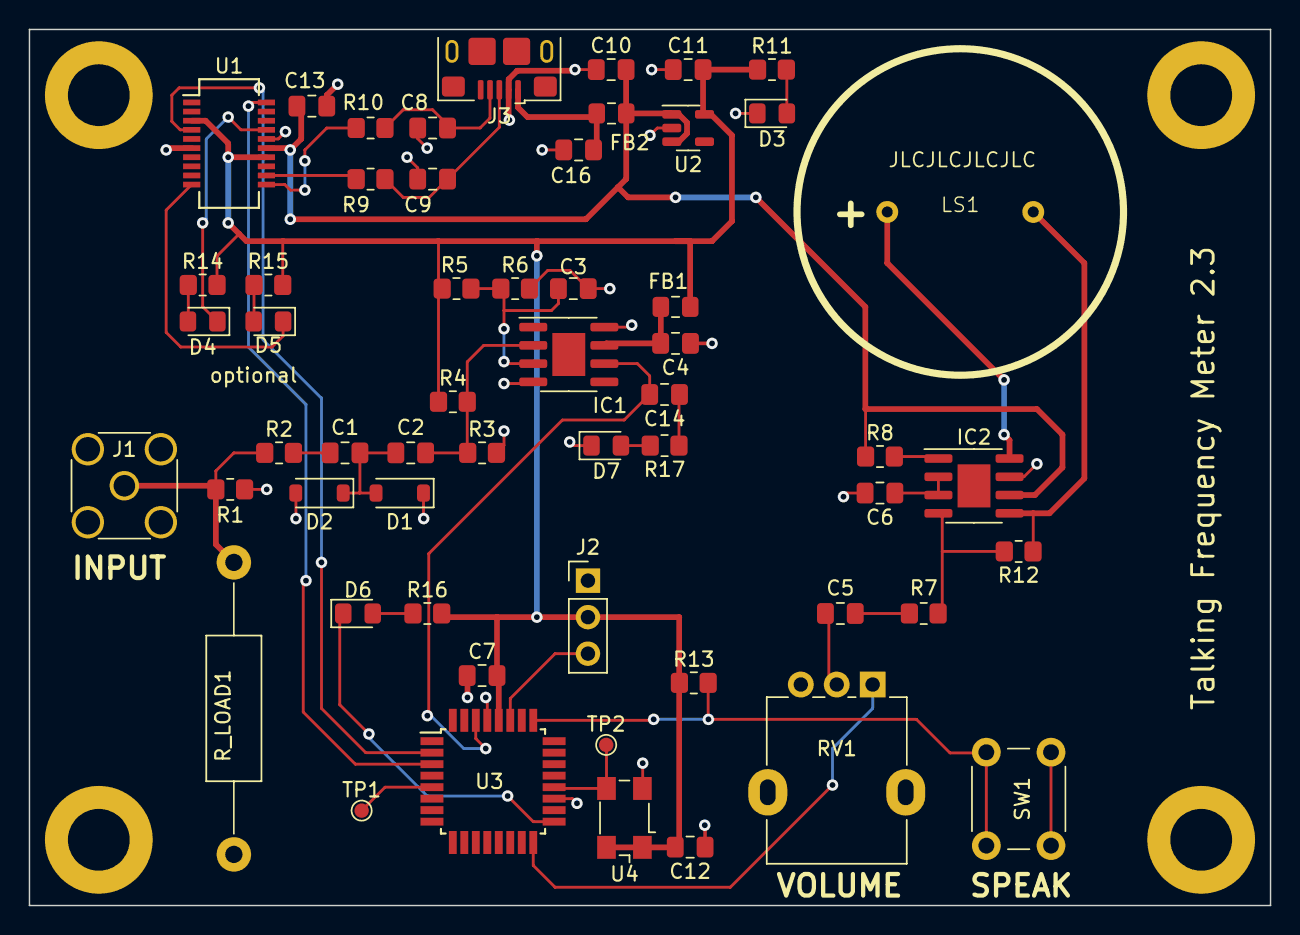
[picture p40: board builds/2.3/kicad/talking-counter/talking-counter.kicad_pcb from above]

Board: 2 copper layers, 86.4 x 61.0 mm, 60 parts (0 on the bottom side), 38 nets.

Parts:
C1, C2, C3, C4, C5, C6, C7, C10, C11, C12, C13, C14, C16: .1u; C_0805_2012Metric_Pad1.18x1.45mm_HandSolder
C8, C9: 47p; C_0805_2012Metric_Pad1.18x1.45mm_HandSolder
D1, D2: D; D_SOD-123
D3: LED_PWR; LED_0805_2012Metric_Pad1.15x1.40mm_HandSolder
D4: RX_LED; LED_0805_2012Metric_Pad1.15x1.40mm_HandSolder
D5: TX_LED; LED_0805_2012Metric_Pad1.15x1.40mm_HandSolder
D6: LED_STATUS; LED_0805_2012Metric_Pad1.15x1.40mm_HandSolder
D7: LED_SIG; LED_0805_2012Metric_Pad1.15x1.40mm_HandSolder
FB1, FB2: Ferrite; L_0805_2012Metric_Pad1.15x1.40mm_HandSolder
H1, H2, H3, H4: MountingHole; MountingHole_4.3mm_M4_DIN965_Pad
IC1: TLV3501AIDR; SOIC-8-1EP_3.9x4.9mm_P1.27mm_EP2.29x3mm
IC2: LM4862MX_NOPB; SOIC-8-1EP_3.9x4.9mm_P1.27mm_EP2.29x3mm
J1: Conn_Coaxial; SMA_Amphenol_132134_Vertical
J2: PROG; PinHeader_1x03_P2.54mm_Vertical
J3: UJ2-MIBH-G-SMT-TR; USB_Micro-B_Amphenol_10118193-0001LF_Horizontal
LS1: Speaker; speaker SM231508
R1: 100k; R_0805_2012Metric_Pad1.20x1.40mm_HandSolder
R2: 1k; R_0805_2012Metric_Pad1.20x1.40mm_HandSolder
R3, R4, R5, R6, R7, R8, R11, R12, R13, R14, R15, R16, R17: 10k; R_0805_2012Metric_Pad1.20x1.40mm_HandSolder
R9, R10: 27; R_0805_2012Metric_Pad1.20x1.40mm_HandSolder
RV1: R_VOL; Potentiometer_Alpha_RD901F-40-00D_Single_Vertical
R_LOAD1: 50; R_Axial_DIN0411_L9.9mm_D3.6mm_P20.32mm_Horizontal
SW1: SW_MEC_5E; SW_PUSH_6mm_H5mm
TP1: CKOUT; TestPoint_Pad_D1.0mm
TP2: 10MHz; TestPoint_Pad_D1.0mm
U1: FT231XS; SSOP-20_3.9x8.7mm_P0.635mm
U2: AP2112K-3.3; SOT-23-5
U3: AVR64DD32; TQFP-32_7x7mm_P0.8mm
U4: FT5HV; Oscillator_SMD_Fox_FT5H_5.0x3.2mm

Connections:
+5V: C10.2, C13.2, FB2.1, IC2.6 (VDD), R8.1, U1.15 (VCC), U2.1 (VIN), U2.3 (EN)
COMP_OUT: C14.2, IC1.6 (OUT), U3.30 (PA0)
DAC: RV1.1, U3.16 (PD6)
GND: C3.2, C4.1, C6.2, C7.1, C8.2, C9.1, C10.1, C11.1, C12.1, C13.1, C16.1, D1.1 (K), D2.2 (A), D3.1 (K), D7.1 (K), IC1.4 (V-), IC1.8 (SHDN), IC2.7 (GND), J1.2 (Ext), J2.1, J3.2, R1.2, R3.2, R6.1, RV1.3, R_LOAD1.2, U1.6 (GND), U1.16 (GND), U2.2 (GND), U3.19 (GND), U3.29 (GND), U4.2 (GND)
MCU_RX: U1.20 (TXD), U3.3 (PA5)
MCU_TX: U1.4 (RXD), U3.2 (PA4)
unnamed: C1.2, R2.2
unnamed: C5.1, R7.2
unnamed: C5.2, RV1.2
unnamed: C8.1, J3.4, R10.2
unnamed: C9.2, J3.3, R9.1
unnamed: C14.1, R17.1
unnamed: C16.2, FB2.2, J3.1
unnamed: C1.1, C2.2, D1.2 (A), D2.1 (K)
unnamed: D3.2 (A), R11.2
unnamed: D4.2 (A), R14.1
unnamed: D4.1 (K), U1.17 (CBUS1)
unnamed: D5.2 (A), R15.1
unnamed: D5.1 (K), U1.10 (CBUS2)
unnamed: D6.2 (A), R16.1
unnamed: D6.1 (K), U3.17 (VREFA/PD7)
unnamed: D7.2 (A), R17.2
unnamed: C3.1, IC1.3 (+IN), R5.1, R6.2
unnamed: C2.1, IC1.2 (-IN), R3.1, R4.2
unnamed: C4.2, FB1.2, IC1.7 (V+)
unnamed: C6.1, IC2.2 (BYPASS), IC2.3 (+IN)
unnamed: IC2.4 (-IN), R7.1, R12.2
unnamed: IC2.1 (SHUTDOWN), R8.2
unnamed: IC2.5 (VO1), LS1.2, R12.1
unnamed: IC2.8 (VO2), LS1.1
unnamed: J1.1 (In), R1.1, R2.1, R_LOAD1.1
unnamed: J2.3, U3.27 (UPDI)
unnamed: R9.2, U1.12 (USBDM)
unnamed: R10.1, U1.11 (USBDP)
unnamed: TP1.1, U3.5 (PA7)
unnamed: R13.2, SW1.2, U3.25 (PF5)
unnamed: TP2.1, U3.20 (XTAL32K1/PF0), U4.3 (OUT)
VCC: C7.2, C11.2, C12.2, FB1.1, J2.2, R4.1, R5.2, R11.1, R13.1, R14.2, R15.2, R16.2, U1.3 (VCCIO), U1.14 (~RESET), U2.5 (VOUT), U3.28 (VDD), U4.1 (VC), U4.4 (VDD)

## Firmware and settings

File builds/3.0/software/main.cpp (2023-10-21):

#define F_CPU 24000000UL

#include <avr/io.h>
#include <util/delay.h>
#include <avr/interrupt.h>

#include "LedManager.h"
#include "NumberSpeaker.h"
#include "SerialManager.h"
#include "ButtonManager.h"

LedManager leds = LedManager();
SerialManager serial = SerialManager();
ButtonManager button = ButtonManager();

volatile uint32_t COUNTER;
volatile uint16_t RTC_COUNT=0;
uint8_t COUNT_NEW = 0;
uint32_t COUNT_NOW = 0;

ISR(TCD0_OVF_vect)
{
	COUNTER+=4096;
	TCD0.INTFLAGS = TCD_OVF_bm;
}

#define WAIT_FOR_SYNC 0

ISR(RTC_CNT_vect){
	
	// set PWM level for analog output
	if (IsPlaying()){
		DAC0.DATA = GetNextAudioLevel() << 8;
	}
	
	// 800 overflows occurs 10 times per second
	RTC_COUNT++;
	if (RTC_COUNT == 800){
		RTC_COUNT = 0;
		TCD0.CTRLE = TCD_SCAPTUREA_bm;
		
		if (WAIT_FOR_SYNC){
			while ((TCD0.STATUS & TCD_CMDRDY_bm) == 0);	// This hangs infinitely if EXTCLK has no signal
			} else {
			_delay_us(100); // Assume sync happened after a bit of time
		}
		
		COUNT_NOW = COUNTER + TCD0.CAPTUREA;
		
		COUNT_NEW = 1;
	}
	
	RTC.INTFLAGS = 0x11; // interrupt handled
}

void setup_system_clock_24MHz(){
	// Use the highest frequency system clock (24 MHz)
	CCP = CCP_IOREG_gc;
	CLKCTRL.OSCHFCTRLA = CLKCTRL_FRQSEL_24M_gc;
}

void setup_DAC(){
	DAC0.CTRLA = DAC_OUTEN_bm | DAC_ENABLE_bm;
}

void setup_extclk_counter(){
	// Enable the highest frequency external clock on pin 30
	CCP = CCP_IOREG_gc;
	CLKCTRL.XOSCHFCTRLA = CLKCTRL_FRQRANGE_32M_gc| CLKCTRL_SELHF_bm | CLKCTRL_ENABLE_bm;
	
	// Setup TCD to count the external clock
	TCD0.CMPBCLR = 0x0FFF; // count to max
	TCD0.CTRLA = TCD_CLKSEL_EXTCLK_gc; // count external clock input
	TCD0.INTCTRL = TCD_OVF_bm; // Enable overflow interrupt
	while (!(TCD0.STATUS & 0x01)); // ENRDY
	TCD0.CTRLA |= TCD_ENABLE_bm; // EXTCLK, enable
}

void setup_rtc_gate(){
	// Enable the RTC
	CCP = CCP_IOREG_gc;
	CLKCTRL.XOSC32KCTRLA = CLKCTRL_SEL_bm | CLKCTRL_ENABLE_bm; // External clock on the XTAL32K1 pin, enable
	
	// Setup the RTC at 10 MHz to interrupt periodically
	// 10 MHz with 128 prescaler is 78,125 ticks/sec
	RTC.CTRLA = RTC_PRESCALER_DIV1_gc | RTC_RTCEN_bm;
	RTC.PER = 1250-1; // 8kHz
	RTC.INTCTRL = RTC_OVF_bm;
	RTC.CLKSEL = RTC_CLKSEL_XTAL32K_gc; // clock in XOSC23K pin
}


uint32_t COUNT_LAST;
uint32_t get_next_count(){
	while(COUNT_NEW == 0){}
	COUNT_NEW = 0;
	
	if (COUNT_NOW >= COUNT_LAST){
		uint32_t COUNT_DIFF = COUNT_NOW - COUNT_LAST;
		COUNT_LAST = COUNT_NOW;
		return COUNT_DIFF * 10;
		} else {
		// an overflow occurred so take the next count
		COUNT_LAST = COUNT_NOW;
		return get_next_count();
	}
}

int main(void)
{
	leds.setup();
	leds.status_on();
	setup_system_clock_24MHz();
	setup_extclk_counter();
	setup_DAC();
	setup_rtc_gate();
	serial.setup();
	button.setup();
	sei(); // Enable global interrupts
	
	_delay_ms(100);
	leds.power_on();
	leds.status_off();
	
	
	serial.write_line_break();
	serial.write_string("Talking frequency counter 3.0");
	serial.write_line_break();
	
	// say the version number
	speak_digit(3);
	speak_point();
	speak_digit(0);
	
	while (1){
		
		uint32_t count = get_next_count();
		
		if (count > 1000000UL){
			leds.signal_on();
			} else {
			leds.signal_off();
		}
		
		serial.write_number_with_commas(count);
		
		if (button.is_down()){
			leds.status_on();
			while(button.is_down()){}
			serial.write_number_with_commas(count);
			speak_mhz(count, 3);
			get_next_count(); // skip a count to make sure the next one is accurate
			leds.status_off();
		}
	}
}

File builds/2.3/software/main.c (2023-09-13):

/*

AVR64DD32 Frequency Counter

Counter:
The signal to be counted is passed into EXTCLK (pin 30)
and is counted asynchronously using PD0.

Time base:
A 10 MHz time base is passed into XTAL32K1 (pin 20) and
divided down so the counter is gated ten times per second.

Audio output:
Waveforms are generated using DAC (pin 16).

Button:
Pin 25 is pulled high. Ground to indicate a button press.

*/
#define F_CPU 24000000UL

#include <avr/io.h>
#include <util/delay.h>
#include <avr/interrupt.h>
#include <avr/cpufunc.h>
#include <avr/pgmspace.h>
#include "NumberSpeaker.h"
#include "Serial.h"

#define setup_led() PORTD.DIRSET = PIN7_bm
#define led_on() PORTD.OUTCLR = PIN7_bm
#define led_off() PORTD.OUTSET = PIN7_bm

volatile uint32_t COUNTER;
ISR(TCD0_OVF_vect)
{
	COUNTER+=4096;
	TCD0.INTFLAGS = TCD_OVF_bm;
}

volatile uint16_t RTC_COUNT=0;
uint8_t COUNT_NEW = 0;
uint32_t COUNT_DISPLAY = 0;
uint32_t COUNT_NOW = 0;
uint32_t COUNT_PREVIOUS = 0;
ISR(RTC_CNT_vect){
	
	// set PWM level for analog output
	if (IsPlaying()){
		DAC0.DATA = GetNextAudioLevel() << 8;
	}
	
	// count ticks to gate counter
	RTC_COUNT++;
	if (RTC_COUNT == 800){
		RTC_COUNT = 0;
		TCD0.CTRLE = TCD_SCAPTUREA_bm;
		
		// Normally we would wait for sync, but this hangs infinitely if EXTCLK has no signal.
		//while ((TCD0.STATUS & TCD_CMDRDY_bm) == 0); // TODO: timeout if EXTCLK not present
		
		// Instead, just wait a bit for sync to happen.
		_delay_us(100);
		
		COUNT_NOW = COUNTER + TCD0.CAPTUREA;
		if (COUNT_NOW < COUNT_PREVIOUS){
			uint32_t diff = 0 - COUNT_PREVIOUS;
			COUNT_NOW += diff;
		}
		COUNT_DISPLAY = COUNT_NOW - COUNT_PREVIOUS;
		COUNT_DISPLAY = COUNT_DISPLAY * 10;
		COUNT_PREVIOUS = COUNT_NOW;
		COUNT_NEW = 1;
	}
	
	RTC.INTFLAGS = 0x11; // interrupt handled
}

void setup_system_clock_24MHz(){
	// Use the highest frequency system clock (24 MHz)
	CCP = CCP_IOREG_gc;
	CLKCTRL.OSCHFCTRLA = CLKCTRL_FRQSEL_24M_gc;
}

void setup_extclk_counter(){
	// Enable the highest frequency external clock on pin 30
	CCP = CCP_IOREG_gc;
	CLKCTRL.XOSCHFCTRLA = CLKCTRL_FRQRANGE_32M_gc| CLKCTRL_SELHF_bm | CLKCTRL_ENABLE_bm;
	
	// Setup TCD to count the external clock
	TCD0.CMPBCLR = 0x0FFF; // count to max
	TCD0.CTRLA = TCD_CLKSEL_EXTCLK_gc; // count external clock input
	TCD0.INTCTRL = TCD_OVF_bm; // Enable overflow interrupt
	while (!(TCD0.STATUS & 0x01)); // ENRDY
	TCD0.CTRLA |= TCD_ENABLE_bm; // EXTCLK, enable
}

void setup_rtc_gate(){
	// Enable the RTC
	CCP = CCP_IOREG_gc;
	CLKCTRL.XOSC32KCTRLA = CLKCTRL_SEL_bm | CLKCTRL_ENABLE_bm; // External clock on the XTAL32K1 pin, enable
	
	// Setup the RTC at 10 MHz to interrupt periodically
	// 10 MHz with 128 prescaler is 78,125 ticks/sec
	RTC.CTRLA = RTC_PRESCALER_DIV1_gc | RTC_RTCEN_bm;
	RTC.PER = 1250-1; // 8kHz
	RTC.INTCTRL = RTC_OVF_bm;
	RTC.CLKSEL = RTC_CLKSEL_XTAL32K_gc; // clock in XOSC23K pin
}

void setup_button(){
	PORTF.DIRCLR = PIN5_bm; // pin 25
	PORTF.PIN5CTRL = PORT_PULLUPEN_bm;
}

uint8_t is_button_down(){
	if (PORTF.IN & PIN5_bm){
		return 0;
		} else {
		return 1;
	}
}

uint8_t is_button_up(){
	if (PORTF.IN & PIN5_bm){
		return 1;
		} else {
		return 0;
	}
}

void wait_for_button_press(){
	while(is_button_up()){} // pin 25
}

void setup_DAC(){
	DAC0.CTRLA = DAC_OUTEN_bm | DAC_ENABLE_bm;
}

int main(void)
{
	setup_system_clock_24MHz();
	setup_serial();
	setup_led();
	setup_extclk_counter();
	setup_rtc_gate();
	setup_DAC();
	setup_button();
	
	sei(); // Enable global interrupts
	
	printf("\r\n");
	printf("\r\n");
	printf("Talking Frequency Counter 2.3");
	printf("\r\n");
	
	led_on();
	speak_digit(2);
	speak_point();
	speak_digit(3);
	_delay_ms(200);
	led_off();
	
	uint8_t count2 = 0;
	
	while (1){
		
		count2 += 1;
		if (count2 >= 10){
			count2 = 0;
		}
		
		while(!COUNT_NEW);
		uint32_t count = COUNT_DISPLAY;
		COUNT_NEW = 0;
		
		if (count > 0){
			led_on();
			} else {
			led_off();
		}
		
		printf("%d ", count2);
		print_with_commas(count);
		
		if (is_button_down()){
			speak_mhz(count, 3);
		}
	}
}

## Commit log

2019-07-26 initial upload
    [ATMega328-usb-counter.kicad_pcb, ATMega328-usb-counter.sch]
2019-07-28 rev 1.2 schematic
    [ATMega328-usb-counter.kicad_pcb, ATMega328-usb-counter.sch]
2019-07-28 rev 1.1 PCB
    [ATMega328-usb-counter.kicad_pcb, ATMega328-usb-counter.sch]
2019-07-28 added screw hole
    [ATMega328-usb-counter.kicad_pcb, ATMega328-usb-counter.sch]
2019-07-28 improve silkscreen
    [ATMega328-usb-counter.kicad_pcb]
2019-07-28 new diode protection
    [ATMega328-usb-counter.kicad_pcb, ATMega328-usb-counter.sch]
2019-07-28 move usb connector to board edge
    [ATMega328-usb-counter.kicad_pcb]
2019-08-02 tested 100Hz update rate
2019-08-02 100Hz tested better
2019-08-04 counter works
    fixed huge glitch caused by PB2 != PB1
    [main.c]
2019-08-04 works well for 1hz
2019-08-04 pull spi lines high
2019-08-04 3.3V regulator note
2019-08-07 100hz pulse counter documentation
    [sample-output.csv]
2022-11-19 counter 2.0
    [usbcounter.kicad_pcb, usbcounter.kicad_sch]
2022-11-19 USB Counter 2.0: add 3.3v regulator
    [usbcounter.kicad_sch]
2022-11-19 2.0: improve wiring
    [usbcounter.kicad_sch]
2022-11-20 3.0: improve annotations
    [usbcounter.kicad_sch]
2022-11-20 3.0: assign footprints
    [usbcounter.kicad_sch]
2022-11-20 2.0: ready to fabricate
    [usbcounter.kicad_pcb, usbcounter.kicad_sch]
2022-11-22 3.0: update frontend
    [usbcounter.kicad_sch]
2022-11-23 2.0: input protection and amplification
    [usbcounter.kicad_sch]
2022-11-23 2.0: update footprints
    [usbcounter.kicad_sch]
2022-11-23 2.0: reset PCB
    using JLCPCB rules
    [usbcounter.kicad_pcb]
2022-11-23 3.0: new board
    [usbcounter.kicad_pcb, usbcounter.kicad_sch]
2022-11-27 2.0: improve layout
    [usbcounter.kicad_pcb]
2022-11-27 move 2.0 -> 2.1
    [usbcounter.kicad_pcb, usbcounter.kicad_sch]
2022-11-28 2.1: gerbers
    [usbcounter-B_Cu.gbl, usbcounter-B_Mask.gbs, usbcounter-B_Paste.gbp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]
2022-11-28 2.1: update PCB file after gerber export
    [usbcounter.kicad_pcb]
2022-12-10 v2.2: start project
    [usbcounter.kicad_pcb, usbcounter.kicad_sch]
2022-12-11 2.2: USB interface schematic
    [usbcounter.kicad_sch]
2022-12-11 2.2: input signal shaper
    [usbcounter.kicad_sch]
2022-12-12 2.2: comparator frontend
    [usbcounter.kicad_sch]
2022-12-14 2.2: update schematic
    [usbcounter.kicad_sch]
2022-12-14 2.2: update footprints
    [usbcounter.kicad_sch]
2022-12-14 2.2 PCB: rough layout and design rules
    [usbcounter.kicad_pcb]
2022-12-14 2.2 PCB: complete
    [usbcounter.kicad_pcb, usbcounter.kicad_sch]
2022-12-15 2.2: gerbers
    [usbcounter-B_Cu.gbl, usbcounter-B_Mask.gbs, usbcounter-B_Paste.gbp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]
2022-12-23 AVRDD64: oscillator and serial
    [main.c]
2023-09-03 frontend amplifier
    [talking-counter.kicad_pcb, talking-counter.kicad_sch]
2023-09-04 update schematic
    [talking-counter.kicad_sch]
2023-09-06 fix erc issues
    [talking-counter.kicad_sch]
2023-09-06 update footprints
    [talking-counter.kicad_sch]
2023-09-06 custom speaker symbol
    [talking-counter.kicad_sch]
2023-09-06 first pass layout
    [talking-counter.kicad_pcb]
2023-09-06 layout pcb
    [talking-counter.kicad_pcb, talking-counter.kicad_sch]
2023-09-06 PCB updates based on DRC
    [talking-counter.kicad_pcb]
2023-09-13 Update speaker SM231508.kicad_mod
2023-09-16 usbc connector
    [talking-counter.kicad_sch]
2023-10-01 create PCB
    [talking-counter.kicad_pcb, talking-counter.kicad_sch]
2023-10-01 update pcb
    [talking-counter.kicad_pcb]
2023-10-01 move labels
    [talking-counter.kicad_pcb]
2023-10-12 use original button wiring
